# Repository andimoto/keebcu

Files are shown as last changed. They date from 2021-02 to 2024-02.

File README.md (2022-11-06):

# keebcu - a customizer for 3d printable keyboard cases

## Keyboard Customizer

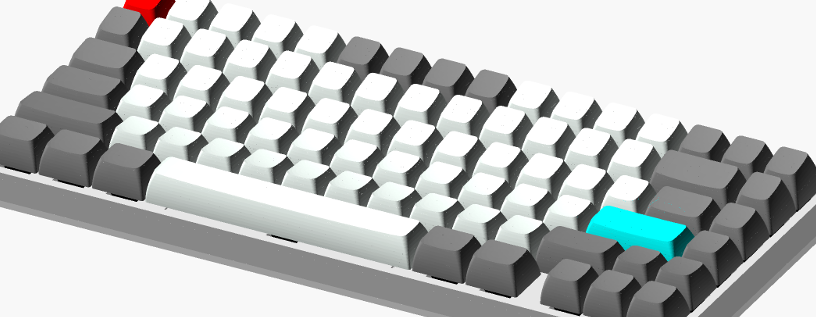
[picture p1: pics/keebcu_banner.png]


### TL;DR usage
```
- clone this repo: git clone https://github.com/andimoto/keebcu.git
- get OpenSCAD (I used 2021.01 and 2019.05 as appImages on Linux).
- open the template_to_copy.scad file in OpenSCAD (or copy and rename it for your own custom layout)
- uncomment 'mainCase(<layout>)' line at the end of the file to check what your are doing
- start customizing your layout (place switch holes and set colors of your keycaps)
- set screw holes where you want them or add even more of them (don't place screw holes near risers on the bottom)
- set usb and pcb values
- set or unset fRowSeparator to move F-Row up
- depending on your printbed size, set where to cut the keyboard case ('cutAfterUnits' & 'spacebarCut')
- (optional) print critical parts of the case like space bar, parts with other stabilizers or usb and pcb area to test everything fits
- generate all necessary model files you want to print by uncomment the proper module call or run the build.sh script
- save as stl file, print and assemble!
- checkout, build and flash firmware firmware https://github.com/andimoto/qmk_firmware/tree/andimoto-keyboards/keyboards/andimoto
```

#### Notes
This is based on *Parametric Cherry MX Mounting Plate for Mechanical Keyboards* by rsheldiii
http://www.thingiverse.com/thing:573578

## Description
This is a OpenSCAD Script for customizing a keyboard with a specific layout. It is designed to show a simulation on how the keyboard could look like by adding keycaps from KeyV2 project by rsheldiii. **So download OpenSCAD and start building your keyboard ;)!**

I designed the keyboard to be printable on smaller 3d printer build plates like Prusa Mini. Therefore, it is possible to configure where the keyboard should be cut by the script with 'cutAfterUnits' variable. With this, it is possible to print a keyboard on smaller printers. The "smallTKL" design is the biggest layout I can print for now. If you have standard size printers like Prusa MK3 or Ender 3, etc, you may print normal TKL or even 100% layouts, eventually :).
The cut will always be around the switch holes. This gives good stability when glueing the parts together. Before glueing, the parts may need some sanding work, etc. Just check that both sides fit to each other without bigger space in between.
(In theory, it should be possible to cut the keyboard into 3 or more parts. Therefore, new modules should be created and the pieces can be calculated by using difference function. This should enable printing bigger sizes like TKL or 100% on smaller printers)

I glued the parts together with Revell CONTACTA glue because of its fine needle which is very practical. Any plastic glue will work. I broke one of my prototype boards for testing and they are pretty stable if glued properly :). I had to use some force for it. Just be sure the case parts are glued well together!

#### Notes
This Keyboard Customizer for OpenSCAD is in "usable" state now, and you can customize your keyboard :). But there are still some imperfections and "bugs". I'm testing several layouts, like normal sized boards to macro pads, etc., from time to time.

Please double check measurements and fittings of your keyboard layout. You first may print some critical parts for testing the model.
The available keyboard models (in stl directory) should work and have been printed by me on a Prusa Mini. I can not give any guarantee on the correct functionality of this script.

### Current designs available
```
- andimoto7583 (printed, documented wiring, firmware ProMicro)
- andimoto6061 (not printed)
- andimoto6064 (printed, documented wiring, firmware ProMicro)
- andimoto_smallTKL (printed)
- andimoto_smallTKL_iso (printed, documented wiring, firmware Teensy2)
- andimoto75Q1iso (printed, documented wiring, firmware Teensy2)
- andimotoTKL (not printed)
- andimotoTKLiso (not printed)
- macropad
- numpad (firmware ProMicro)
```

__Note:__
```
7583 is -> 75% layout with 83 switches.
6061 is -> 60% layout with 61 switches
smallTKL is TKL keyboard with one missing column
75Q1iso -> 75+% with Keychron Q1 Layout
TKL - ten keyless
etc.
```

## Create your own keyboard layout
You can copy the file "template_to_copy.scad", rename it and start configuring your own layout. By uncomment the module calls at the end of the layout file, it is possible to create each part like "right & left case", "right & left lid", and also risers. It is also possible to create the whole keyboard itself in one piece if you can print bigger parts.

If you want to simulate the keyboard with keycaps and its colors, you can clone rsheldiii's KeyV2 Repository
( https://github.com/rsheldiii/KeyV2 ) in parallel to this repository (thisRepo/..).
The SCAD script will include "../KeyV2/includes.scad". So just put it into the right directory.
Keycap styles can be replaced in the module "KeyboardSim('layout','simulation true/false')" itself. See KeyV2 Wiki for available keycap profiles and documentation.

So you can change the colors and have a look at how your keyboard may look like!
You can add more keys into the array, but maybe the case will not fit automatically. Adjust 'height' and 'width' of the case, then.
I will try to implement some more automatic functionalities from time to time.

The keyboard layout is defined in an array. In the template file it is called "template_ansiUS_7583" for example.
It describes (in Units):
```
    [ [xPos (Column) , yPos (Row)] , key size (in Unit), color ]
```

A unit is the size of the cutout for a cherry mx style switch. So, for example, a normal key is 1u,
backspace is 2u or spacebar is for example 6.25u. The size of the cutout for the switch is defined as 'lkey'.

You need to configure 'hight' and 'width' of the case in summury of units. For example: a 5x2 macropad would have width of 5 and a height of 2. These variables are necessary for calculating case sizes. Maybe this will be automated, as the information should be calculatable from the layout array.

The 'layout' array variable holds all integer values, including x.5 values in y direction (like numpad enter). Any else switch hole needs to be integrated in the function/module 'extraCutoutHook'. See ISO layout for an example. In this module any 'unaligned' switch hole can be integrated. Properly to that, the module 'extraKeySimHook' allows to integrade additional simulations, like special keycap simulation like IsoEnter, etc.

After configuring your layout, you can adjust and modify the array 'screwHoleArray' to set the scew holes to the right place you want them to. The lid will also use this array, and thus, the screw holes will fit automaticaly to the case. The standard screw size is 3mm. The length depends on the case height, but I used 3x8mm cylinder head screws for my keyboards.

It is also possible to modify the pcb dimensions with the 'pcb'-values. Available sizes for Arduino Pro Micro and Teensy2 are included. Just change the comments to select the right one. I recommend to measure your pcb anyway and check dimensions. You can also move the whole pcb and cutout for usb connection in X direction by setting 'pcbShift' with a positive or negative value.

Generating risers for the keyboard can be selected with true/false and adjusted in width and length/depth. The colors of the risers and of cource the case and lid can be set after the screw hole array, at the end of the layout file.

With the variable 'fRowSeparator' you can select if the F-Row or the most upper Row (key[0][1]==0) will be moved upwards by a half key unit. See example 'andimotoTKL_iso'. When selecting 'true' some modules will call 'getExtraFRow()' function to get the value to move F-Row upwards.

If the keyboard should get a skirt you can set 'skirtSelect' to true. This enables calculation of an additional skirt around the keyboard. The parameters 'skirtX', 'skirtY' and 'caseRadius' define the skirts dimensions and the radius of the edges.

## Build STL Files
I added the script 'build.sh' for building all necessary parts of a keyboard at once. It reads 'conf/module-calls.conf' and places each call at the end of the keyboard file to render it and safe it in the stl directory. The output is saved in stl directory under the keyboard name.

```
NOTE: openscad command should be in $PATH or the environment variable OPENSCADBINPATH should be set to the OpenSCAD binary.
For example:
                export OPENSCADBINPATH=/home/<user>/<pathToBinary>/OpenSCAD-2021.01-x86_64.AppImage
```

```
build.sh parameter:

./build.sh <keyboard name> <config file>
    - keyboard name: name of the keyboard file without .scad extension
    - (optional) config file: mymodules.conf (any file name is possible, just add the proper syntax)

for example:
    ./build.sh andimotoTKL

    or

    /build.sh andimoto6061 myModuleCalls.conf
```

```
NOTE: do not remove this line from the keyboard file and do not place this line in between the configuration variables

              /* ###################### BUILD_LINE ########################*/
```

### build.sh description
The build.sh script checks if OpenSCAD binary is available. If not, user has to set OPENSCADBINPATH to point to the binary.
Then it checks parameters. The 1st parameter is necessary and tells the name of the keyboard to build. The script then appends .scad extension automaticaly and uses the name for the output directory. No keyboard file name provided, will stop the script and return an error. Then it checks optional parameter of config file. Default config file will be used if no 2nd parameter is given.

Each keyboard file has a separator at the end: "BUILD_LINE". The script greps for the line number of the separator and prints out the keyboard file until this line number. This output will be saved in an temporary directory which will be removed after build. Also, and output directory will be generated to save stl files in it.
Then it places each module call from the config file at the end and calls OpenSCAD with the generated file to render the stl part. After this it places the next module call and generates the next stl, an so on.

You can add your own config file with the module calls you want and call the build.sh script with the config file as 2nd parameter. If no 2nd parameter is given, the script uses default config file 'conf/module-calls.conf'. The script greps for 'module' and separates the line at ':'. The last part will be used and appended to the created scad file.

```
config file syntax:
  module1: mainCase(layout);
  module2: lidR();
  module3: myOwnModuleCall(withParam);
```

__This was only tested on Linux Mint 19.3 (Ubuntu 18.04) and Linux Mint 20 (Ubuntu 20.04).__

## Parts needed
- Printed Keyboard Parts
  - Case
  - Lids
  - Risers
- __Cherry MX Style switches__
- __Costar Stabilizers__
- __Fancy Keycaps__
- __Teensy2 or Arduino Pro Micro__
- 12x Cylinder Head Screws 3x8mm for lids
- 20x Cylinder Head Screws 2.5x8mm for frame (if frame is selected)
- Thin wires
- 1N4148 diodes

__Note:__ Parts can be bougth from ebay, amazon, etc. There is a great choice, but also many things are not available or in stock...

## Assembly
- Use sandpaper and a scalpel to clear the surface where parts get glued together. Double check if parts do not block each other.
- Glue the two case parts together carefully. Place them on a flat surface and put some books on each side, then put some glue into the rills.
- Wait until it is dry and put some more glue on it if needed.
- After some drying time you can put in the switches (it is possible that this will bend the keyboard)
  - Maybe you need to add more glue when keyboard is bended
  - Switches which will have stabilizers should be set with the champfer downwards. Champfer is where LED placement is on the switch. Then the stabilizers have space inside the keycaps.
- Solder switches and diodes together (see directory wiring_sheets)
  - Checkout qmk guide for handwiring -> https://beta.docs.qmk.fm/using-qmk/guides/keyboard-building/hand_wire
- Solder the controller onto the keyboard matrix and place the pcb inside the pcb holder of the lid.
- Build, flash and test your firmware (you can use this for testing https://keyboardchecker.com/)
- Screw all parts together and place the risers if you need them (I recommend gluing the risers on the lids and then assembly them to the case)
- If you use Costar Stabilizers, place the stabilizers downwards.
- Have fun with your keyboard and start building your next keyboard ;)

## Printing advises
- Use brim for keyboard case. As there are many holes, the plate adhesion can be weak and the corners can rise up a little bit.
- Be careful with color changes. If color change is only at height of case stabilizer (not keycap stabilizers!!) or screw holes, there can be problems when screwing on the lid. I broke the top part of the scrw cylinder where the color change had no good adhesion the other layers. I recommend to do the color change at the last layer of the keyboard cases plate as seen [here](https://github.com/andimoto/keebcu/tree/master/pics/img/screwHolesColorChange.jpg)
  - Place color changes on the upper layer of the plate of the case. With this the walls have more adhesion on previous layers as seen [here](https://github.com/andimoto/keebcu/blob/master/pics/img/IMG_20210406_151457.jpg)
  - Note: though this issue may be fixed with the oval spacers for the screws, double check the stability of the screw holes by printing a small prototyp with color change where you want it.
- Notice, when placing the switches into the plate, the keyboard case will bend (mid up, sides down) there is the variable 'switchHoleTolerance' which you can modifiy if needed. This could reduce this kind of bending, but also make the switches more loose.
- Normally the lid parts do not need any brim.
- Check if your printer prints right-angled. I had issues with my Prusa Mini printing exact squared parts. More info [here](https://forum.prusaprinters.org/forum/how-do-i-print-this-printing-help/how-to-fix-bending-of-a-box/).

## todo
- create selectable space (in y direction) between function row and next rows (DONE: fRowSeparator)
- provide pcb cutout for teensy 2.0 (DONE)
- add delta variable for usb cutout and pcb-holder to move it. (DONE)
- avoid case stabilizer for iso enter and numpad enter (optional)
- add cherry style stabilizer!
- add a selectable skirt to the case (DONE)
- add parametric keebCase (in progress, should be already usable)
- screw holes get crossed by case stabilizer (DONE / screw hole standoffs have also an oval shape now)
- documentation for keebCase.scad (always in progress)
- add build script (DONE)
- other build system (make or docker, etc.)
- test other keyboard layouts like random stuff or ten keys (always in progress)
- make screw stems (spacers for screwing lid in) rotateable (DONE: screwSpacerRotation in degree)
- move inner horizontal case stabilizers in vertical direction (DONE: set caseStabMov Var)

## Wrist rest and Keyboard Case
For each keyboard a wrist rest can be created with the model file wrist.scad. The stl-directory contains a wrist rest for each keyboard which can be printed as you want.
For transportation I designed a case which can be customized in size to fit your keyboard. The case has placeholders for little magnets and gets locked by some kind of bones :).

__Attention: The Keyboard case is still in development state. I just printed some smaller prototypes. But it fits well so far. Need to check magnets.__

## Firmware
For firmware please see https://github.com/andimoto/qmk_firmware/tree/andimoto-keyboards/keyboards/andimoto

The qmk_firmware fork contains everything to build the firmware for the provided boards *andimoto7583* and *andimoto_smallTKL*.

**Attention: The Pro Micro is "normally" suited for layouts with up to 65 switches. I was lazy and did not want to modify the pcb cutout to fit in the teensy 2.0 at that time. So I removed both TX/RX Leds from the pro micro and had 2 extra pins available (pcb may be damaged!!). This enables layouts with up to 84 switches :). Also qmk_layout needs to be squeezed together.**

*I will also add a schematic for soldering the keyboard matrix and the Pro Micro of the available boards.*

Available wiring diagrams for:
- andimoto6064 with Arduino Pro Micro
- andimoto7583 with Arduino Pro Micro
- andimotoSmallTKL_iso with Teensy 2.0
- andimoto75Q1iso with Teensy 2.0

The Arduino Pro Micro clones are very cheap so I used them. More money for fancy keycaps ;).

## Model Gallery
*andimoto7583*
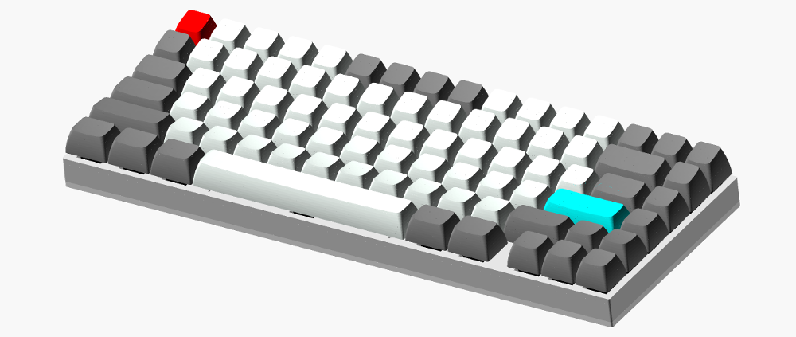
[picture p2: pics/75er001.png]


*andimoto smallTKL iso*
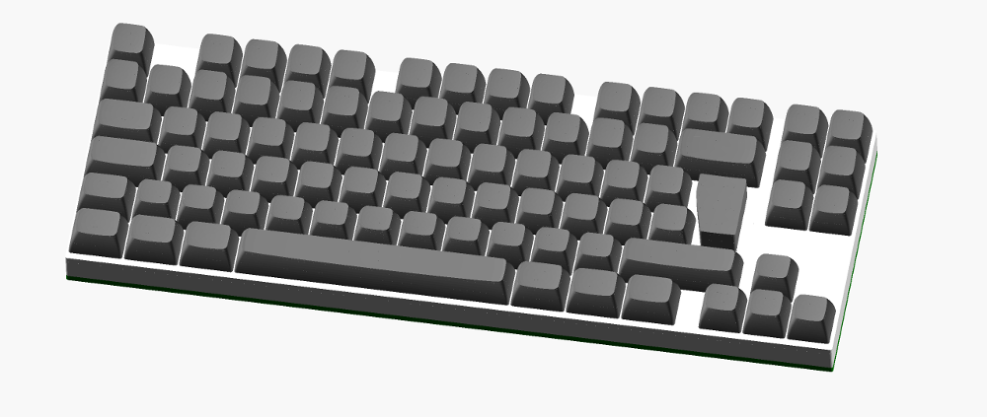
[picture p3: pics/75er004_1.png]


*andimoto smallTKL*
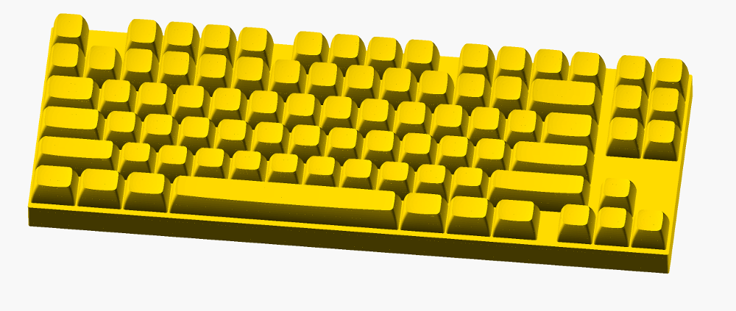
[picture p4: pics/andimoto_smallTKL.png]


*andimoto smallTKL_iso*
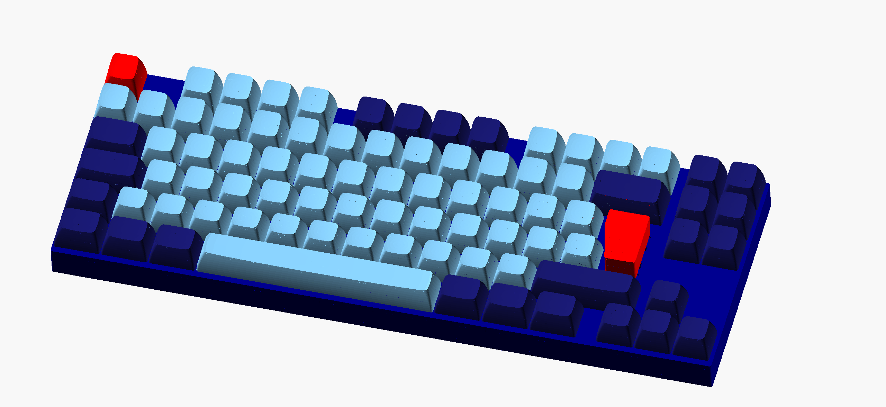
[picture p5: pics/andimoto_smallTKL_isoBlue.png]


*andimoto6061*
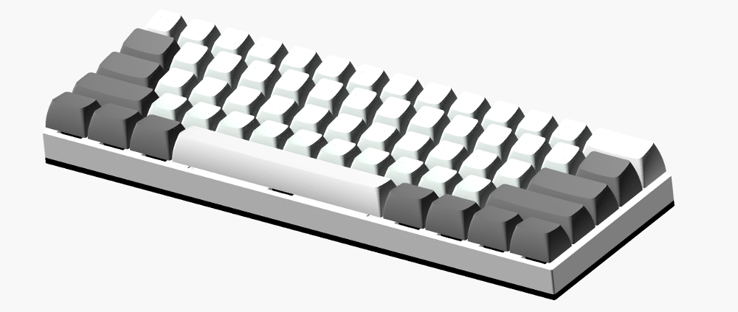
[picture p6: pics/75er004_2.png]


*andimotoTKL*
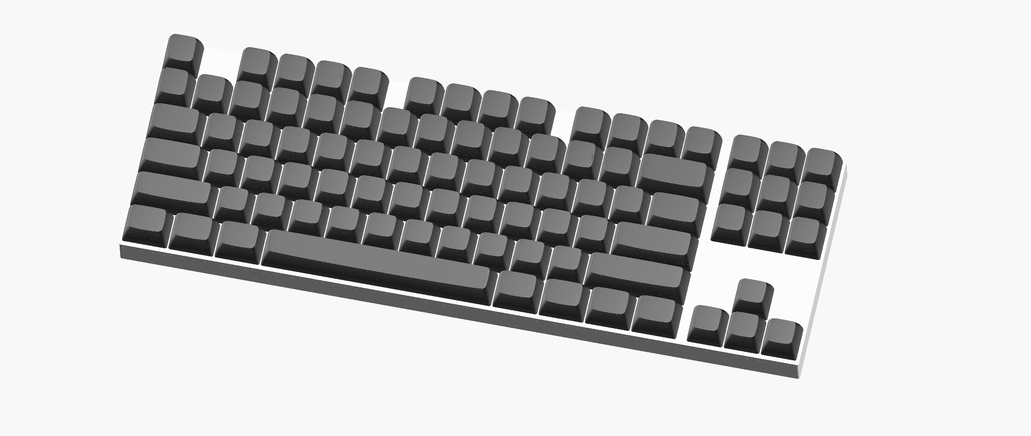
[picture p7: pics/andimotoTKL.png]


*andimotoTKLiso*
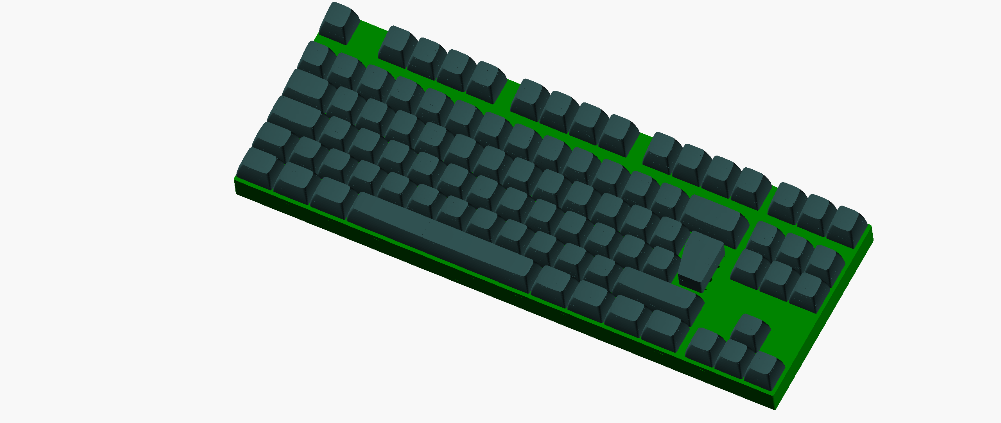
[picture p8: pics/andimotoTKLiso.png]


*andimoto75Q1iso*
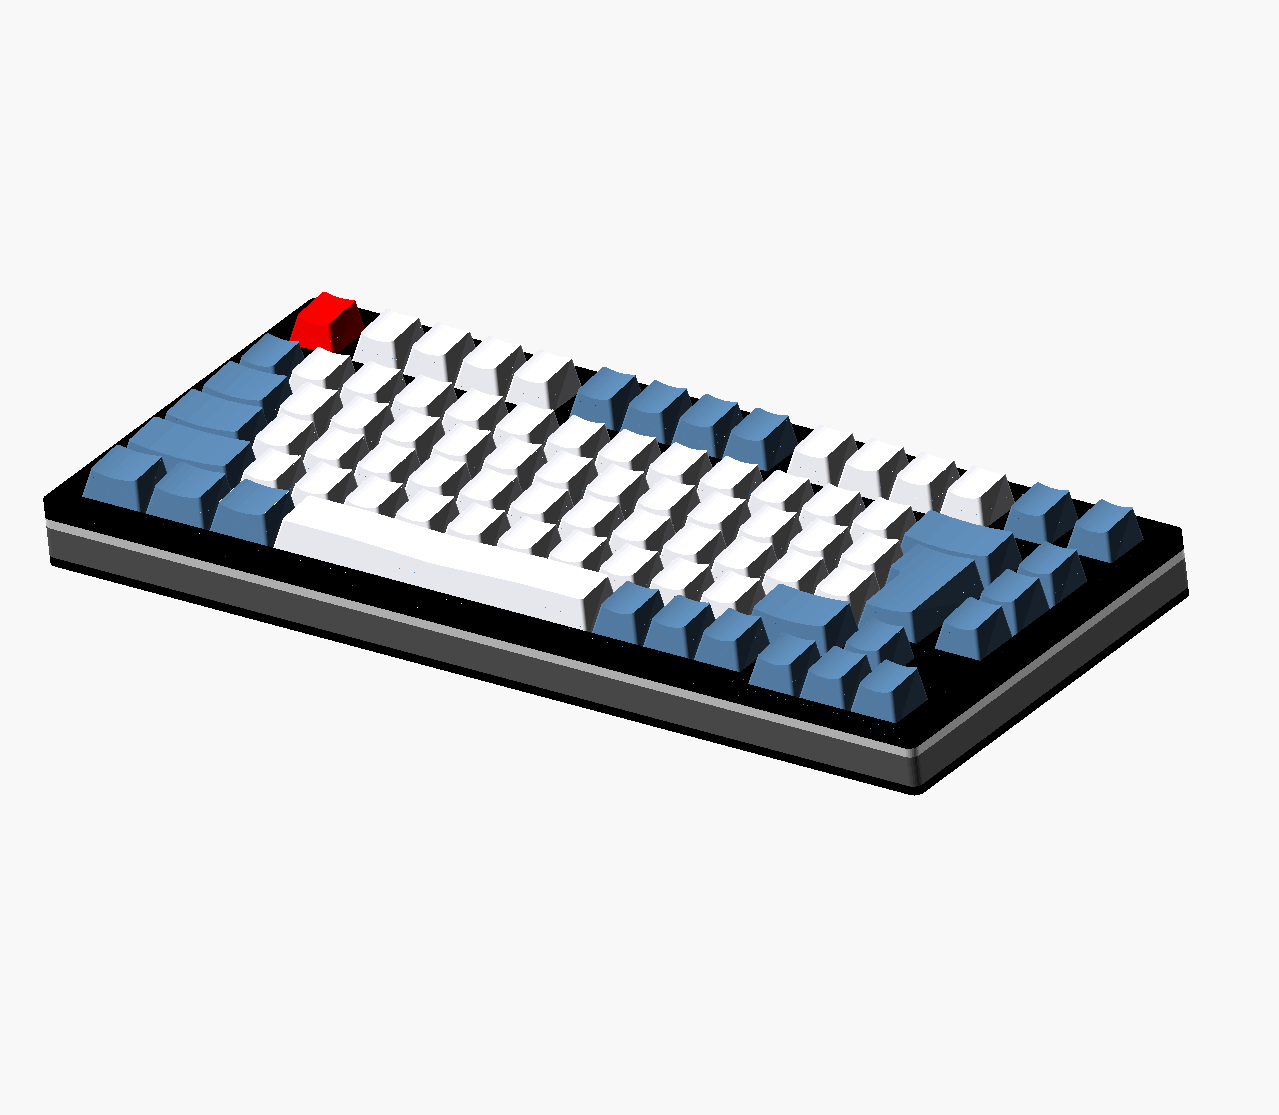
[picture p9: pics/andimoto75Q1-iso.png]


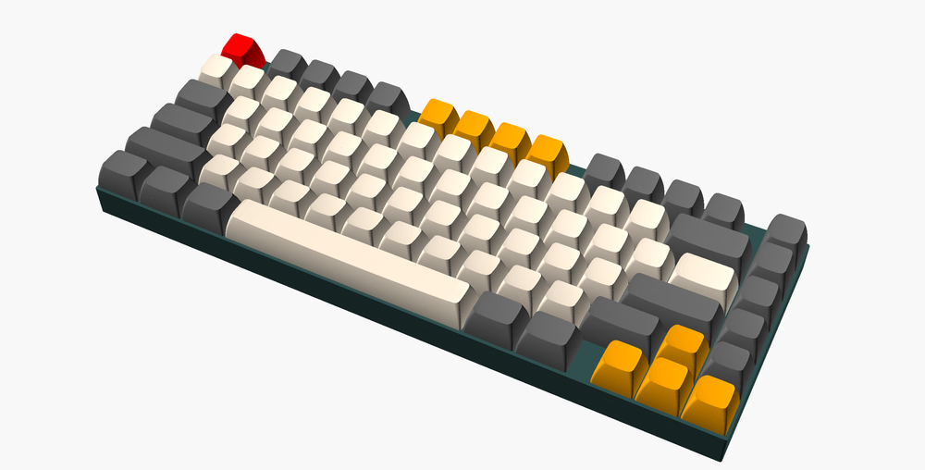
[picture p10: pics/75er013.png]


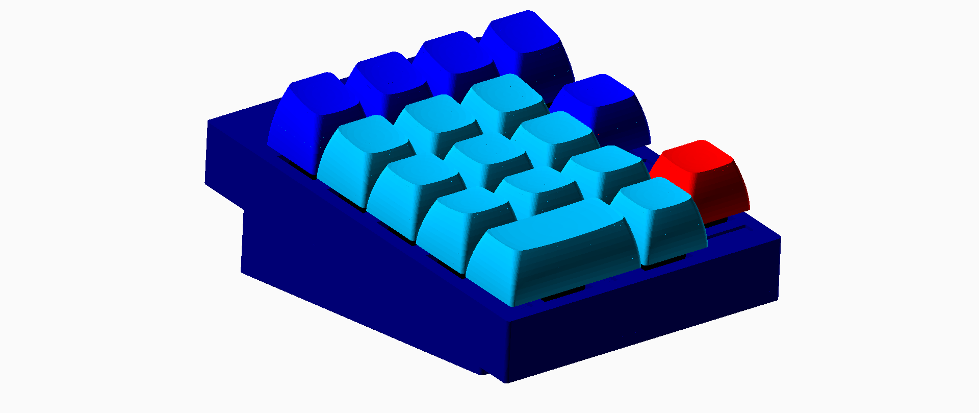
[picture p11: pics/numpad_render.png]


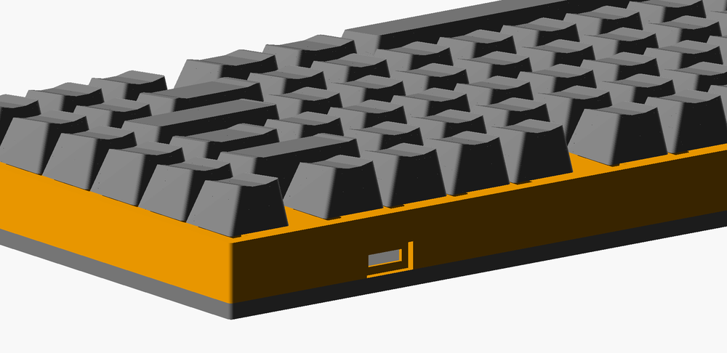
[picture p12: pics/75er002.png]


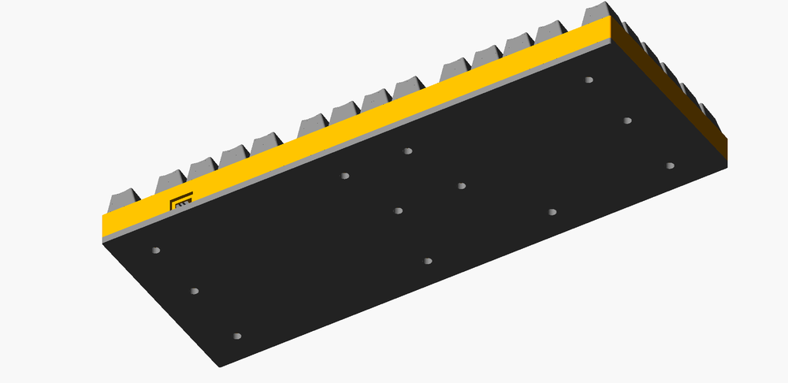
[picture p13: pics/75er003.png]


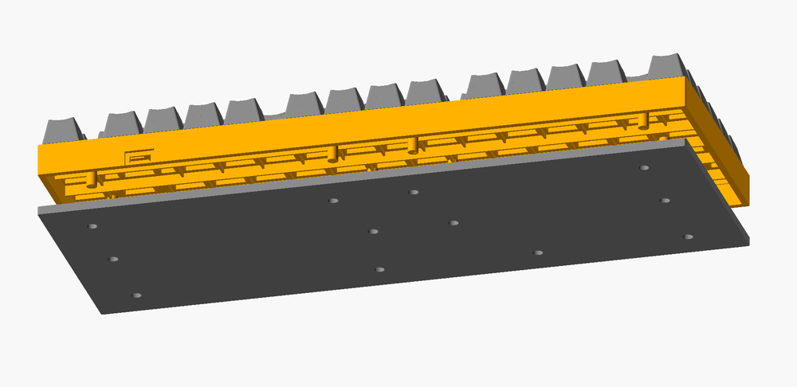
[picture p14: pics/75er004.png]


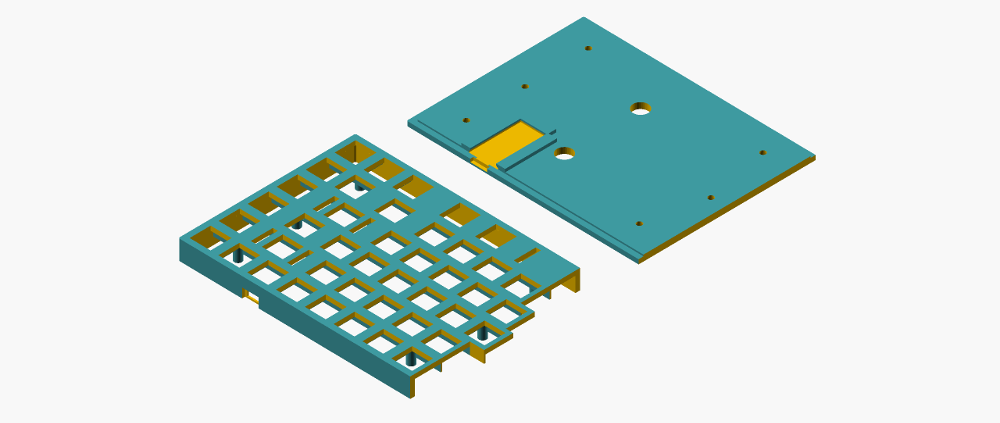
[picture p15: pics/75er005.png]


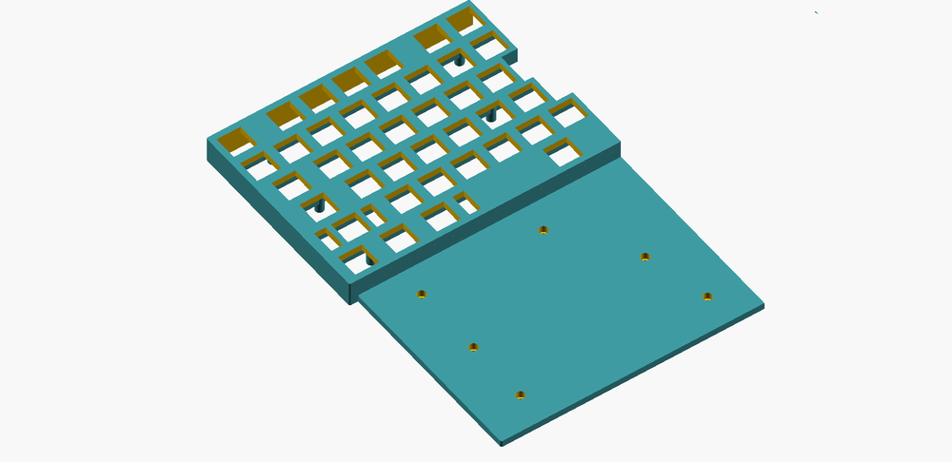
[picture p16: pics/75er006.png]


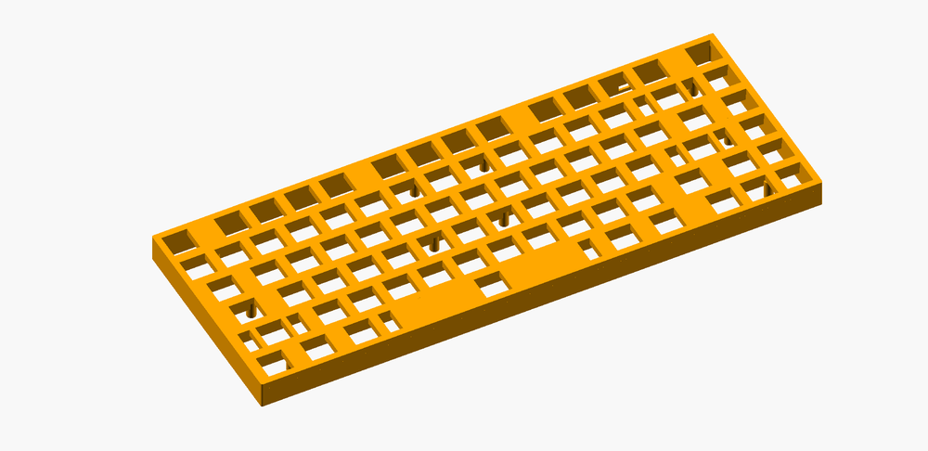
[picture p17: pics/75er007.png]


*andimoto smallTKL_iso case*
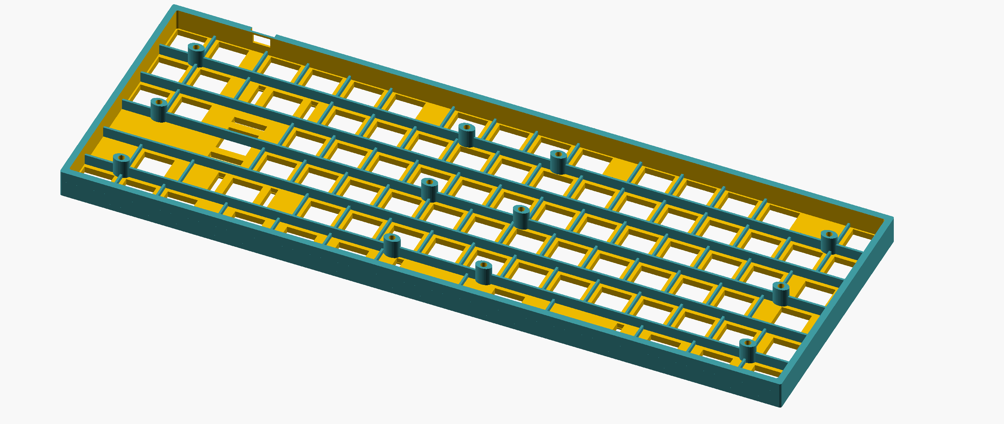
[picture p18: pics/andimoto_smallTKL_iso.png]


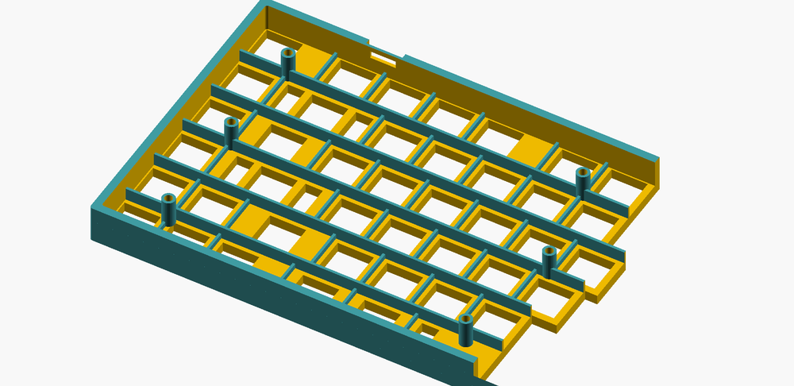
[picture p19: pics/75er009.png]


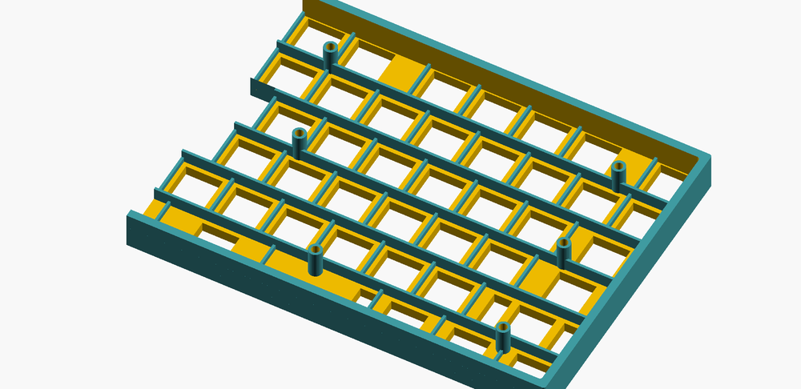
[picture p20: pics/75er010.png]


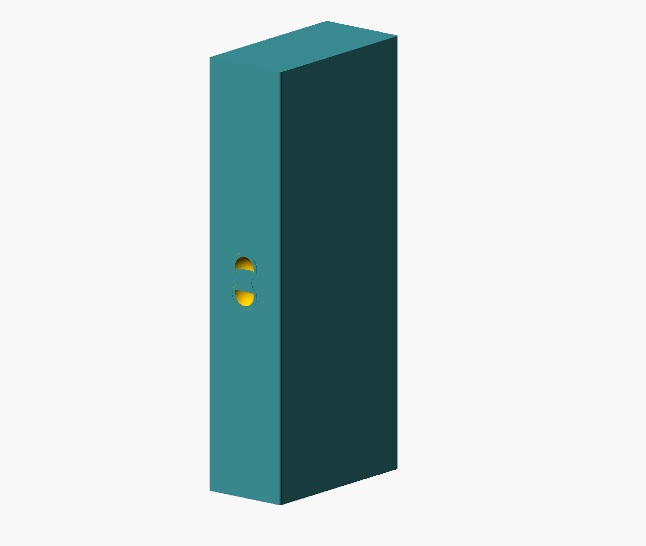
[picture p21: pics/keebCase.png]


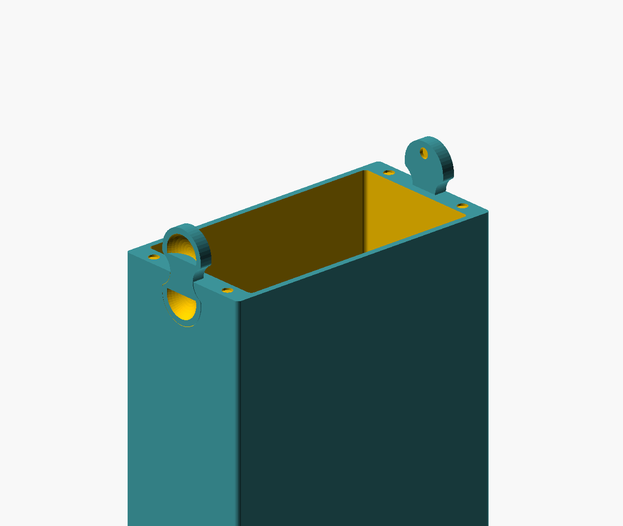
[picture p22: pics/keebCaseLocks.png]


<br>

### -------- ___Reality___ --------

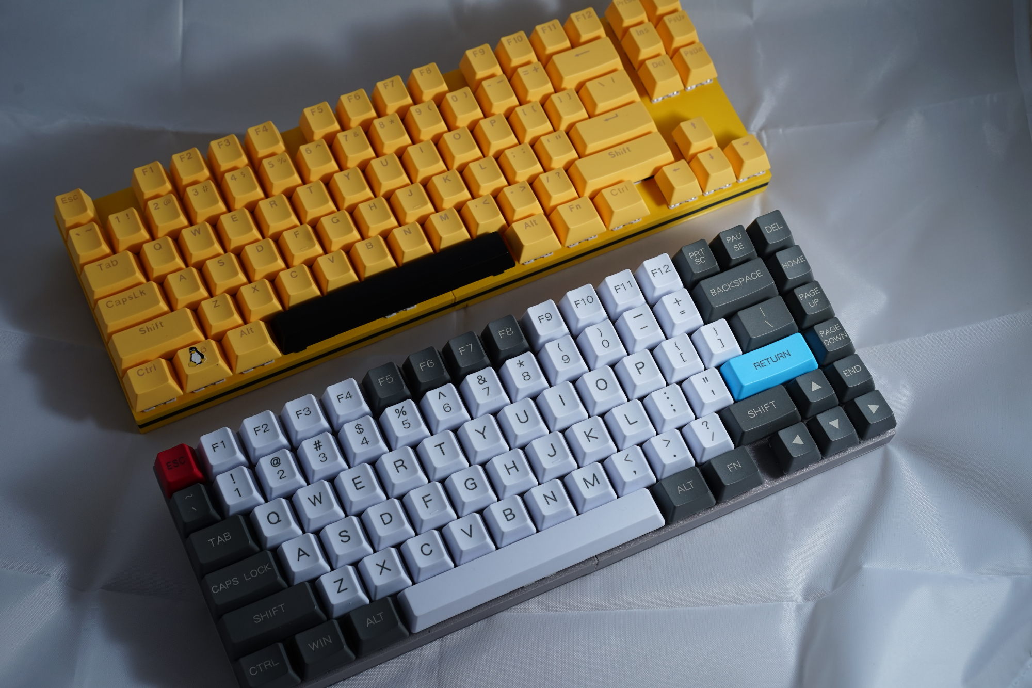
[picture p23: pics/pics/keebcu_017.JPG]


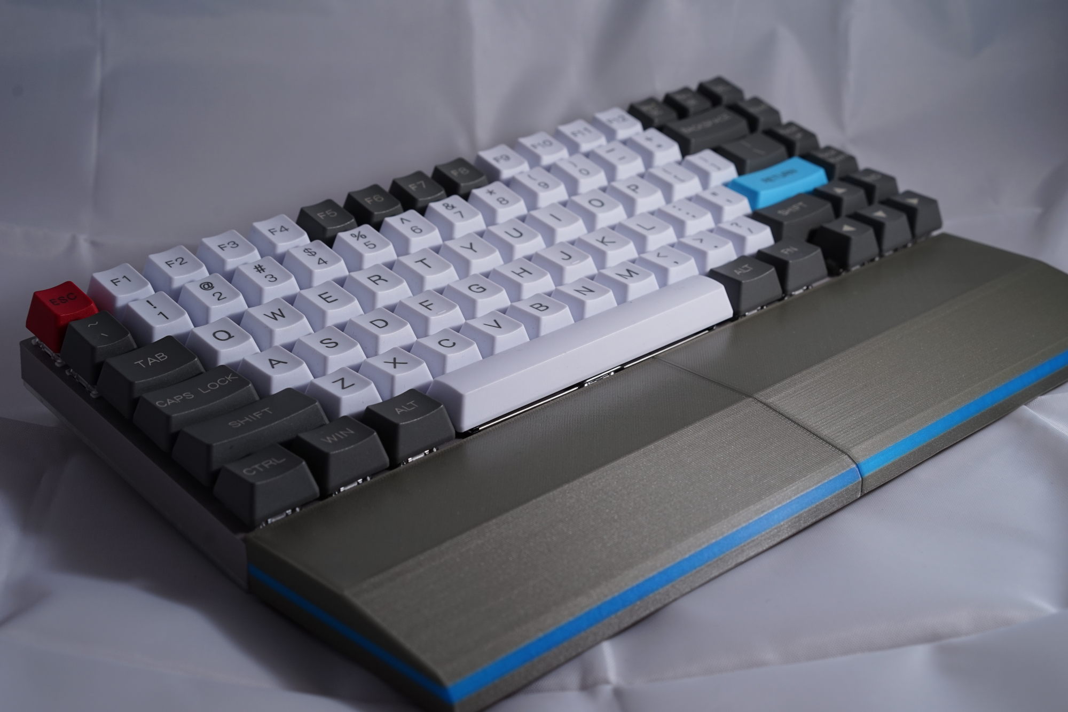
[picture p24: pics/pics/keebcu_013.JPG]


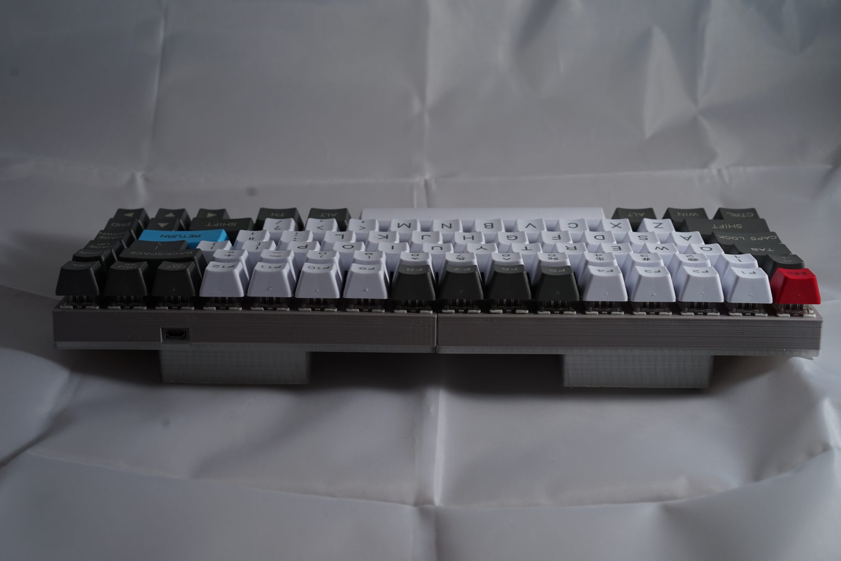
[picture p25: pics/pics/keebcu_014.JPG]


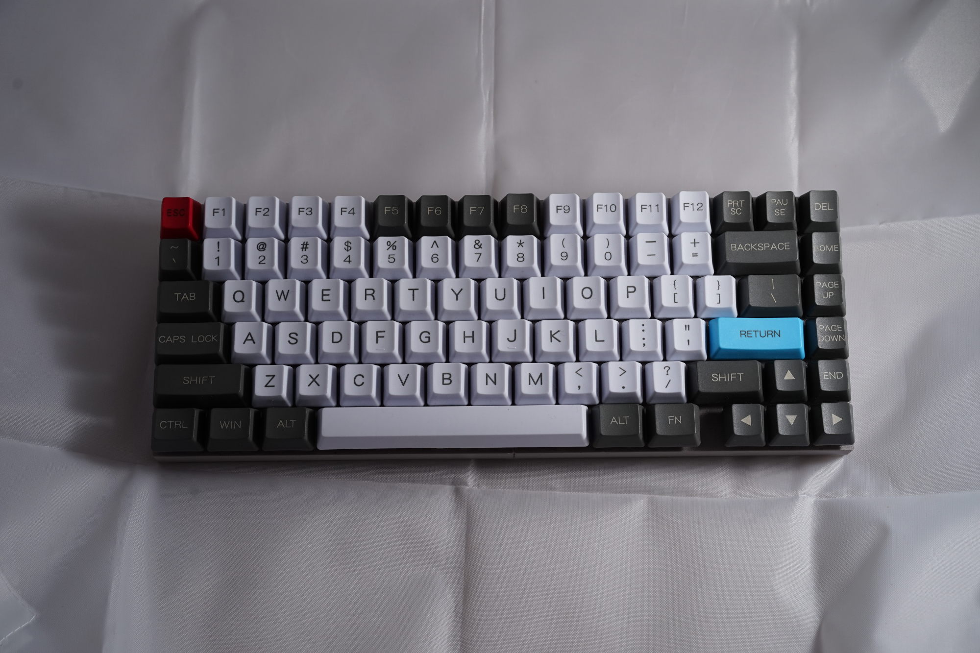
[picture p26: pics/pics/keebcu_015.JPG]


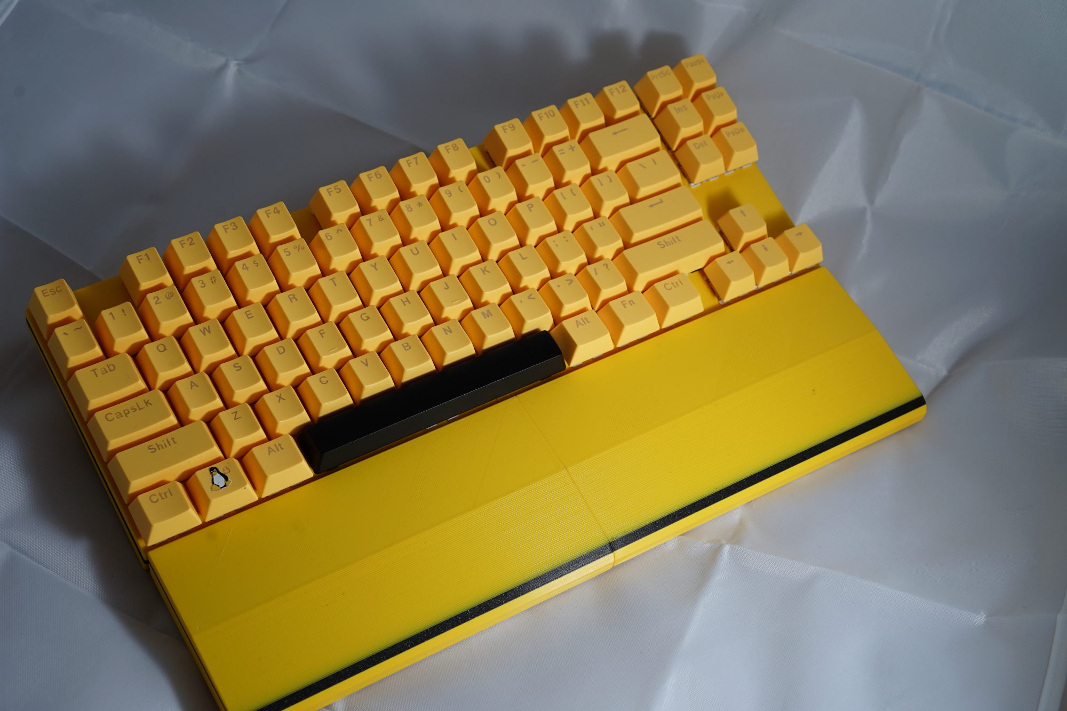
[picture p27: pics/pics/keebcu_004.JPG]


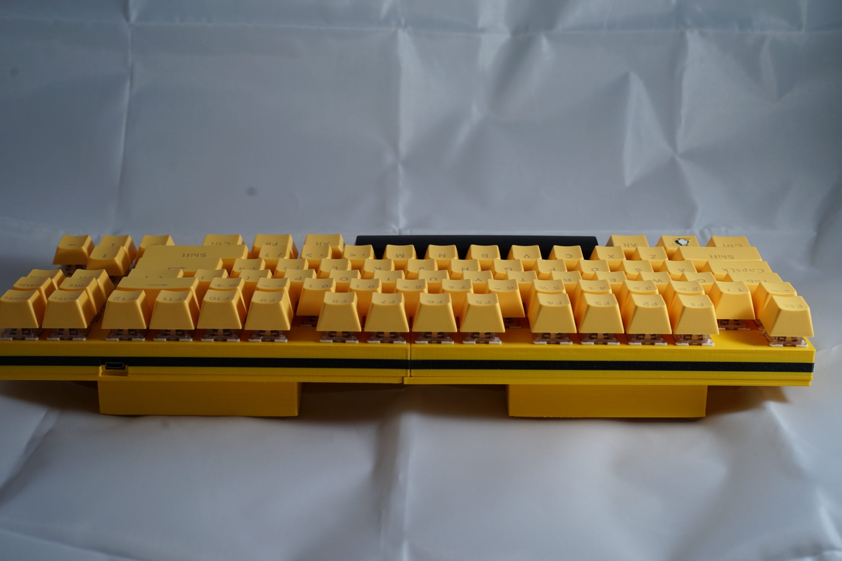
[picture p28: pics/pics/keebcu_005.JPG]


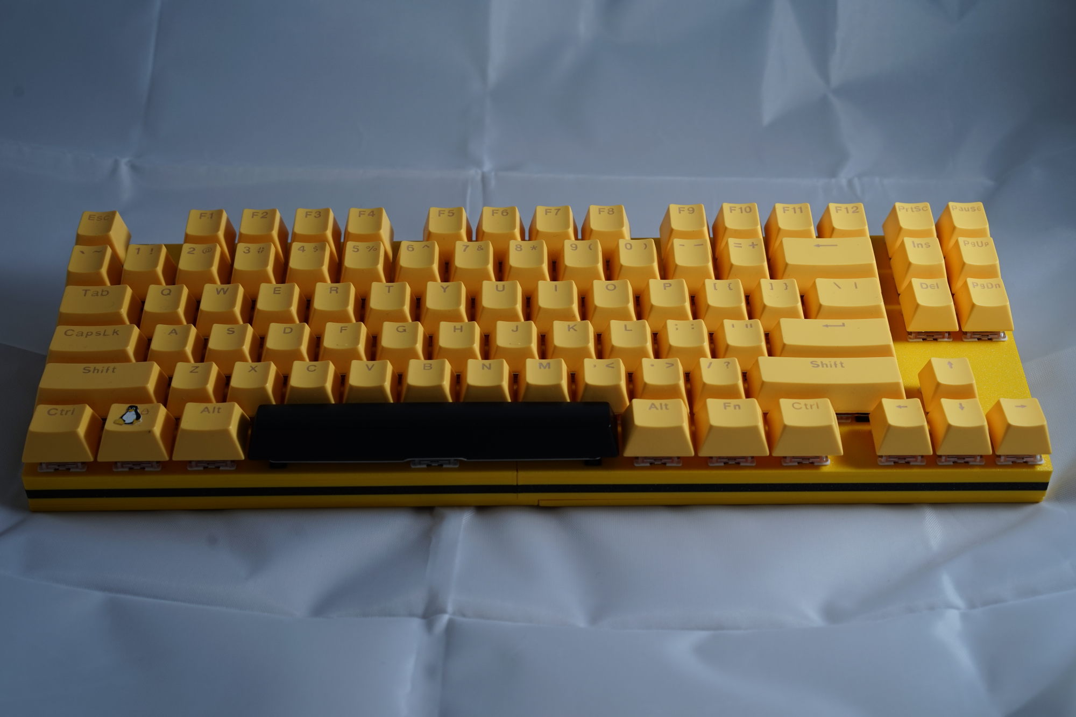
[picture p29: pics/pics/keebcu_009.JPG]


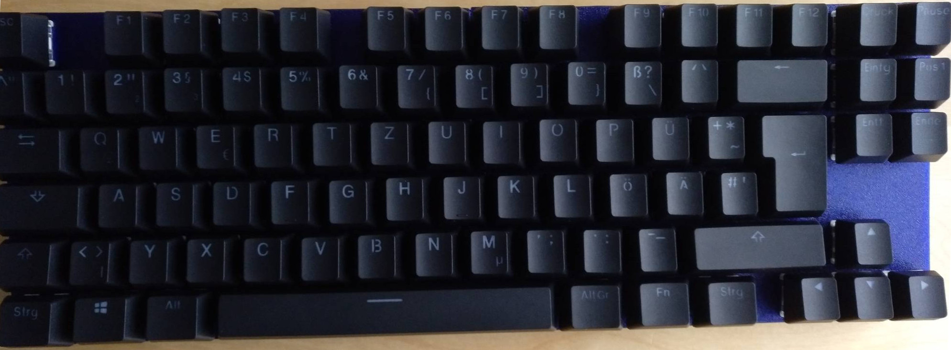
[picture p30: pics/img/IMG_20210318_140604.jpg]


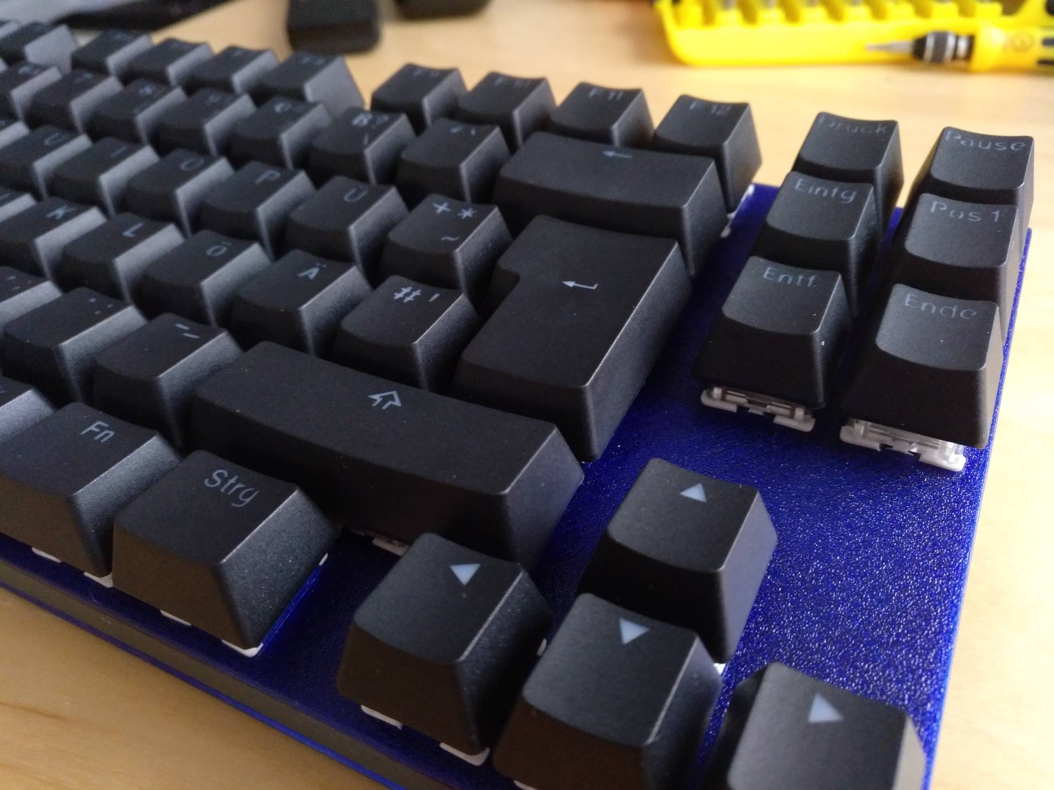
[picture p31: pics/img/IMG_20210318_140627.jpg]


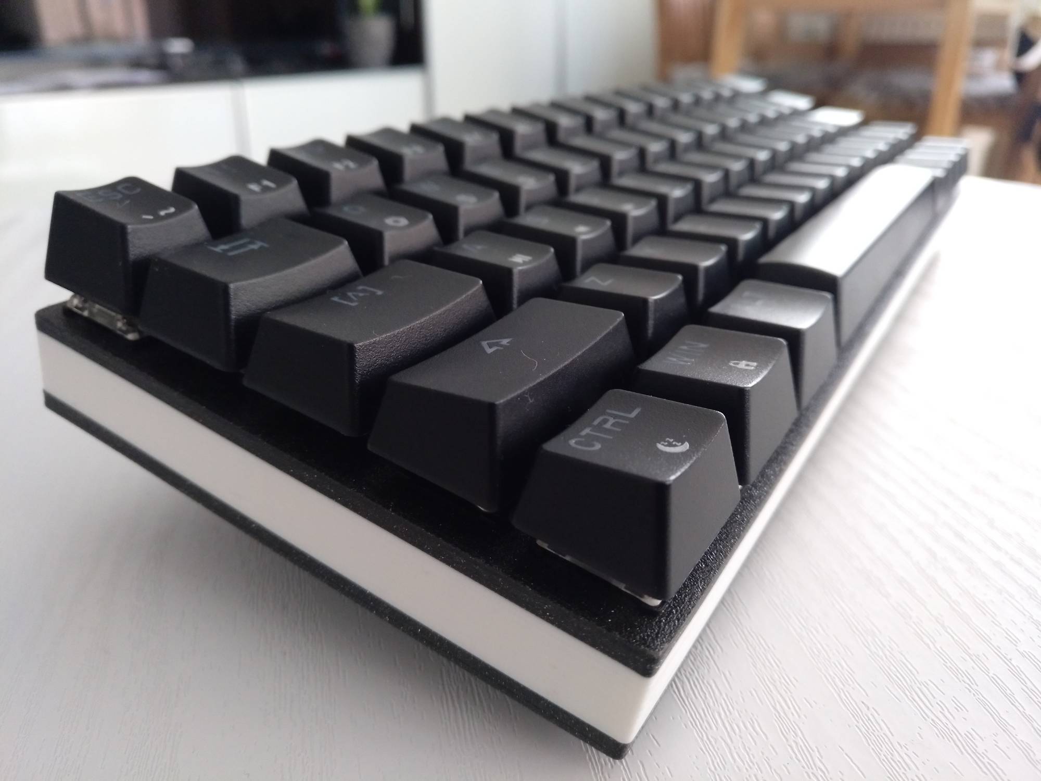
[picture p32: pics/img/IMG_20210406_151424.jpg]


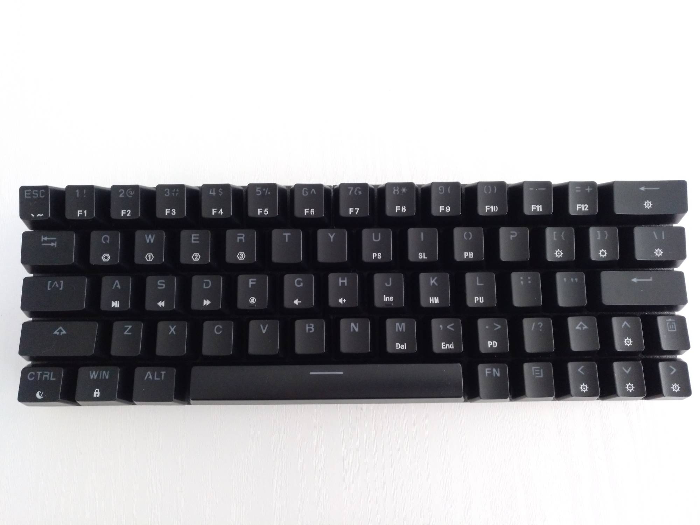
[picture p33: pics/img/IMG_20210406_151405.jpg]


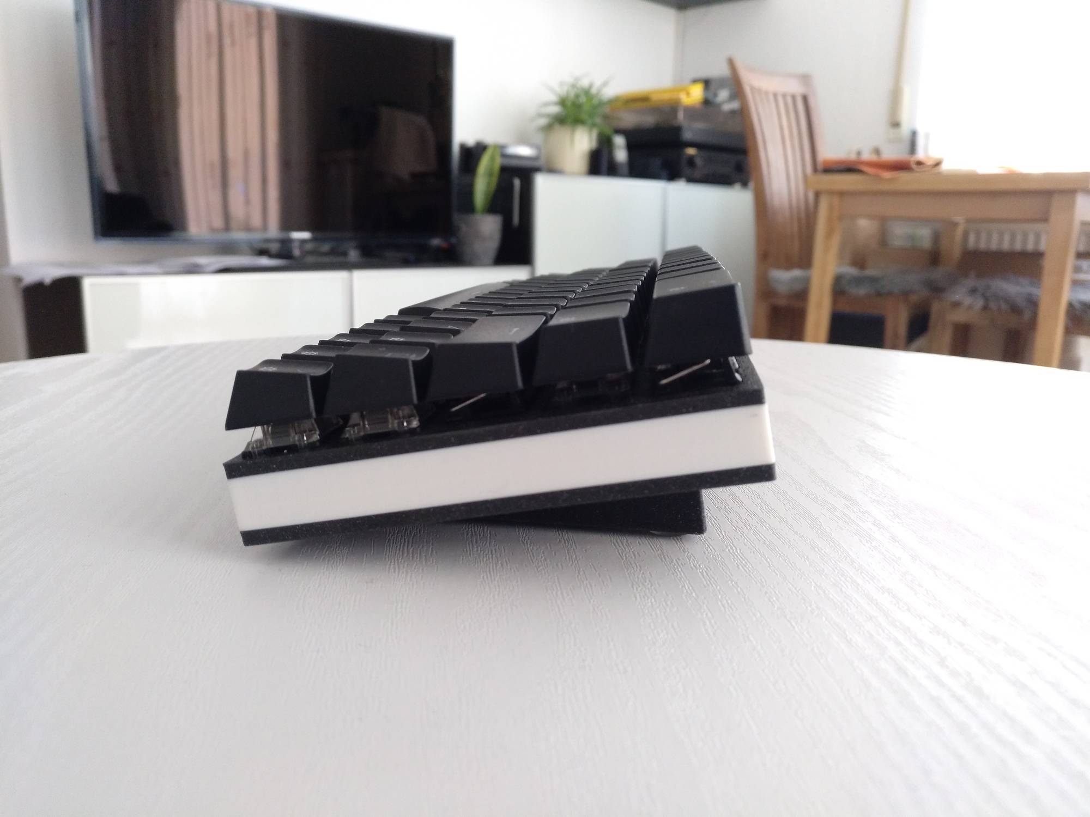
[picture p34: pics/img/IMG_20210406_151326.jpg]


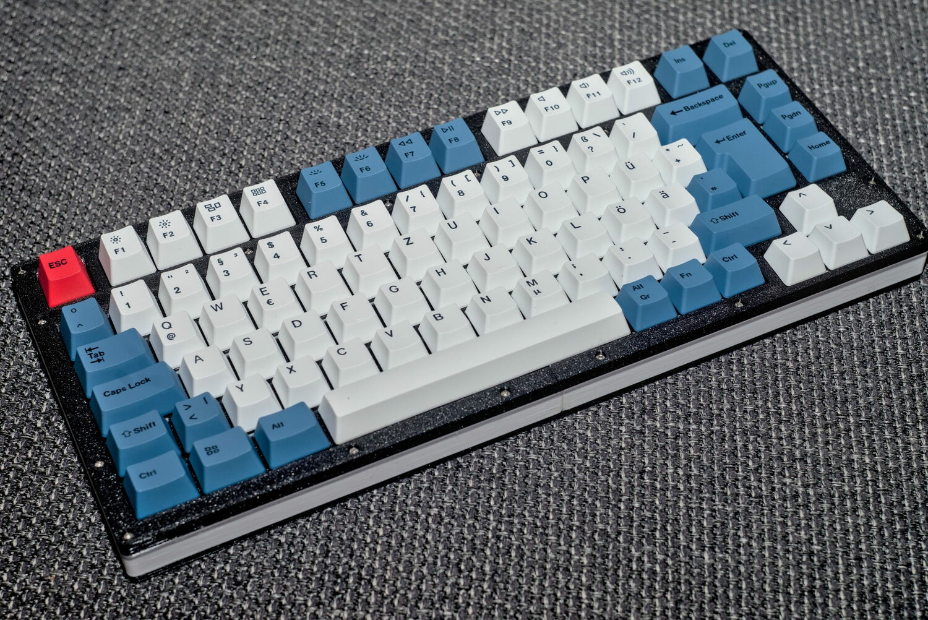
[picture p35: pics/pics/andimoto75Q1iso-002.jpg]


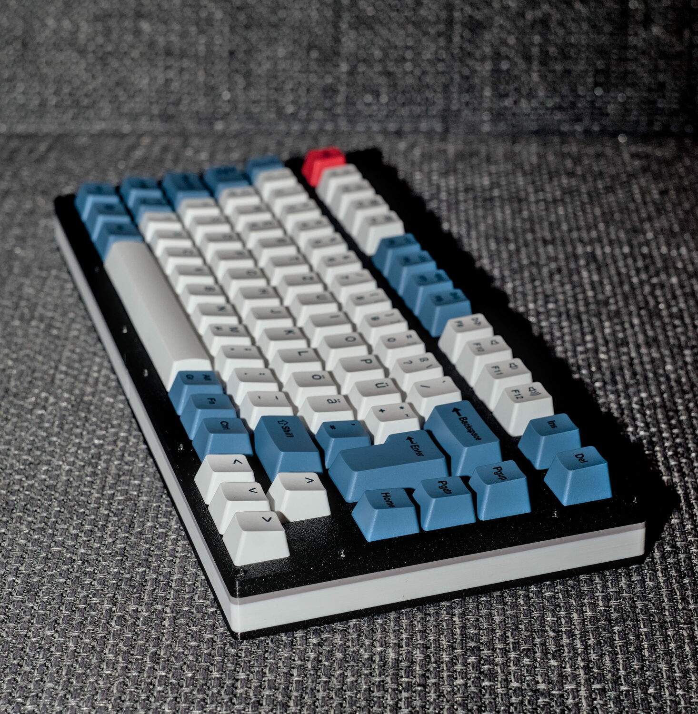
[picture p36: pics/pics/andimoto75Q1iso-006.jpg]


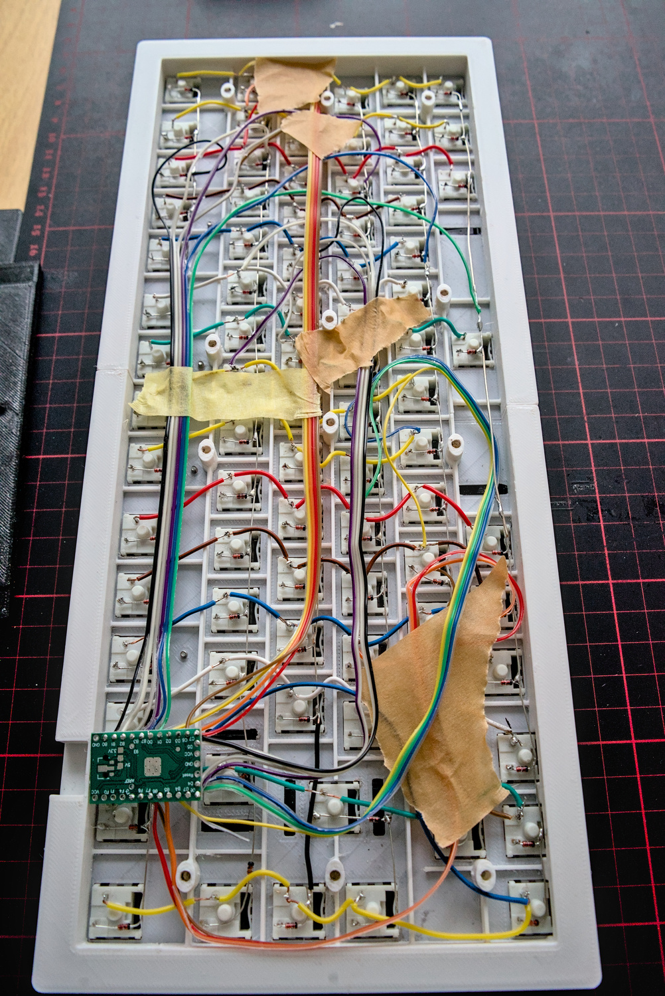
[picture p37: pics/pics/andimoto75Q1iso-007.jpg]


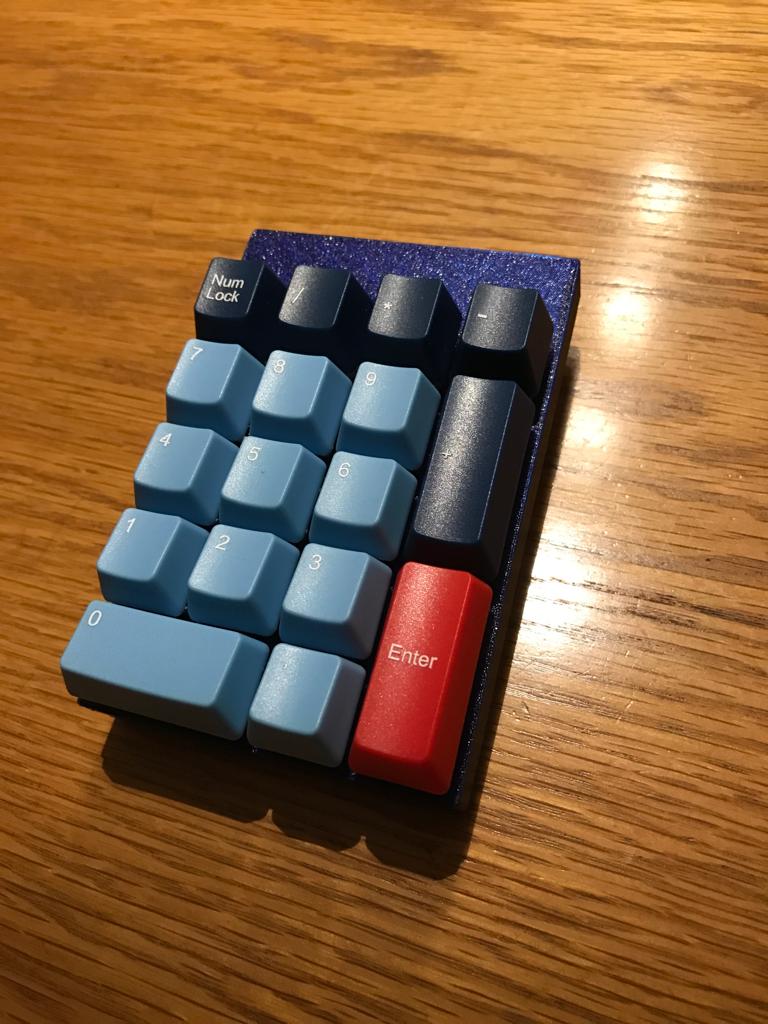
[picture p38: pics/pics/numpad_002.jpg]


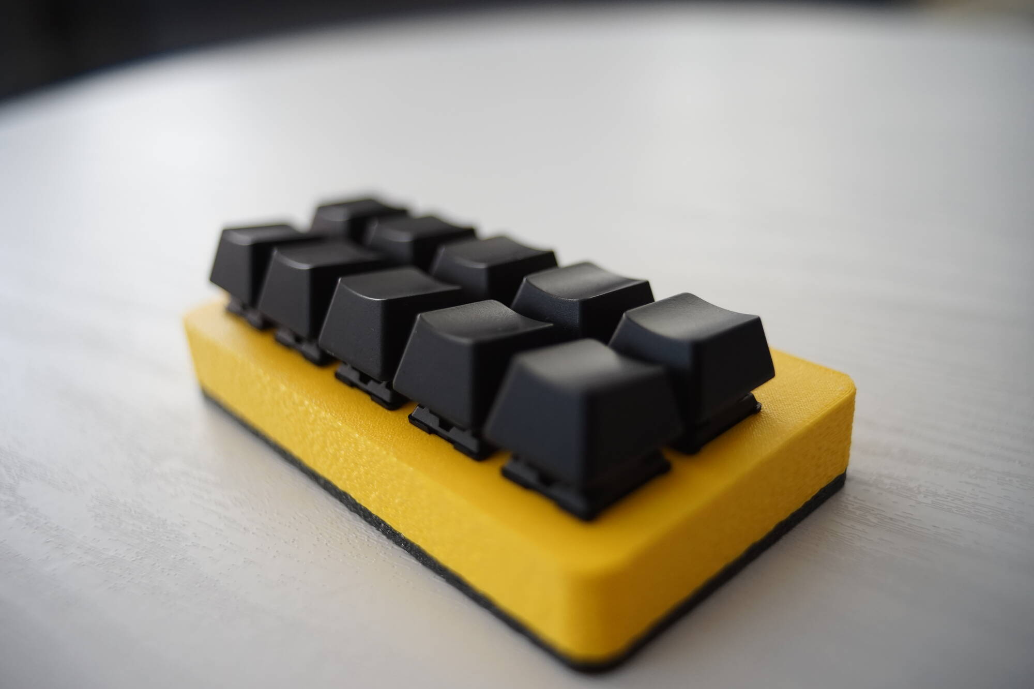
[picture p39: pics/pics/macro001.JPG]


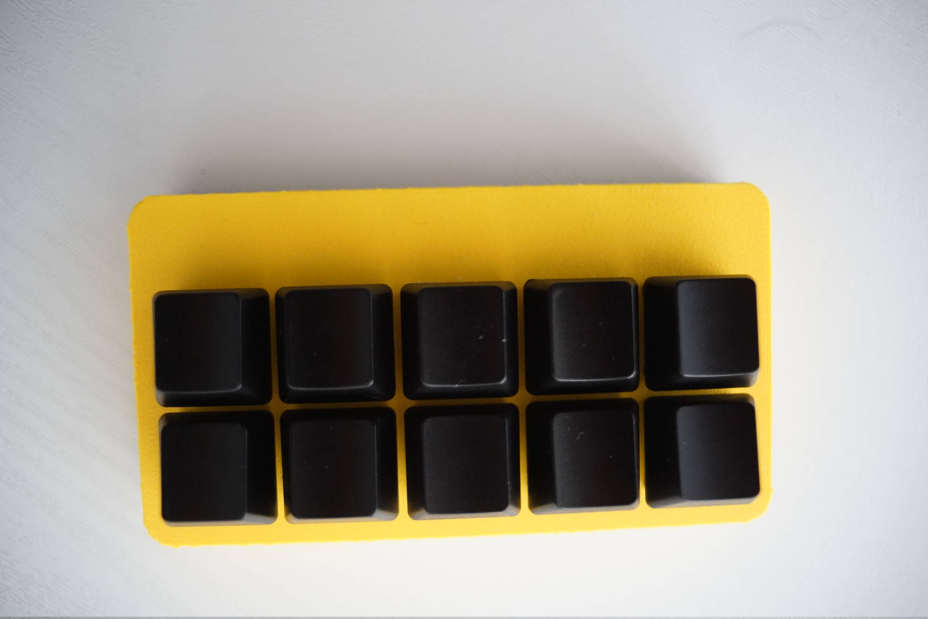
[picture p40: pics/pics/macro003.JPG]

*5x2 macropad printed with fuzzing on outer walls*


### -------- ___Development Process___ --------













# LICENSE

<br />Dieses Werk ist lizenziert unter einer <a rel="license" href="http://creativecommons.org/licenses/by-sa/4.0/">Creative Commons Namensnennung - Weitergabe unter gleichen Bedingungen 4.0 International Lizenz</a>.

<br />This work is licensed under a <a rel="license" href="http://creativecommons.org/licenses/by-sa/4.0/">Creative Commons Attribution-ShareAlike 4.0 International License</a>.

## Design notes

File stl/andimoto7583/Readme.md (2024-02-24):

Added lid without holder for pcb. Just the top of the pcb holder was removed. The pocket for the pcb is still there.
Files are marked with *CNC

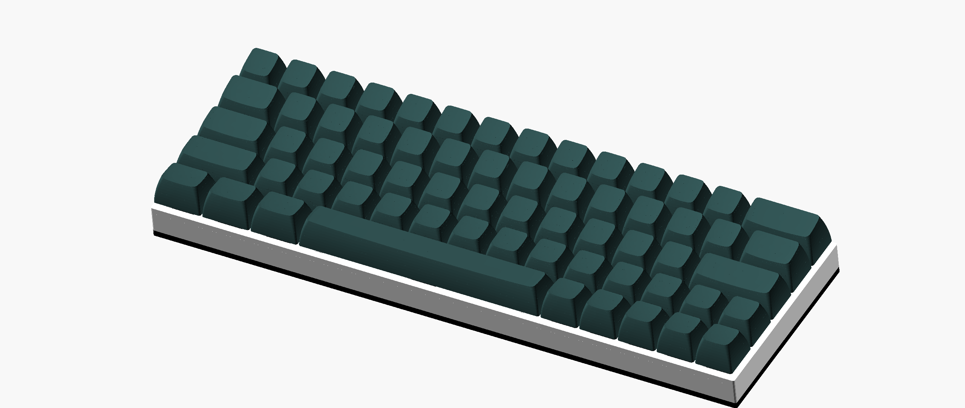
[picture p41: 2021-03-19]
pics/andimoto6064.png

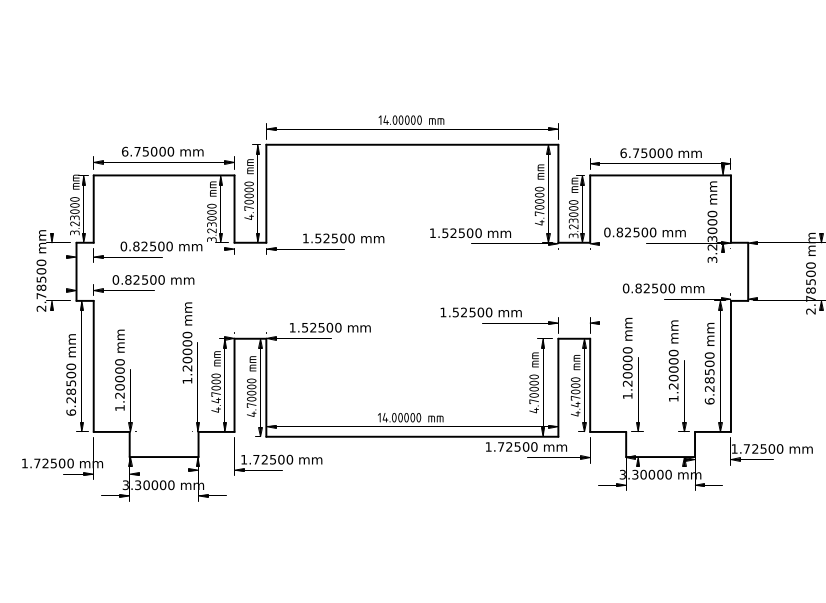
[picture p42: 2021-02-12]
pics/stab-key-sizes-cherry.png

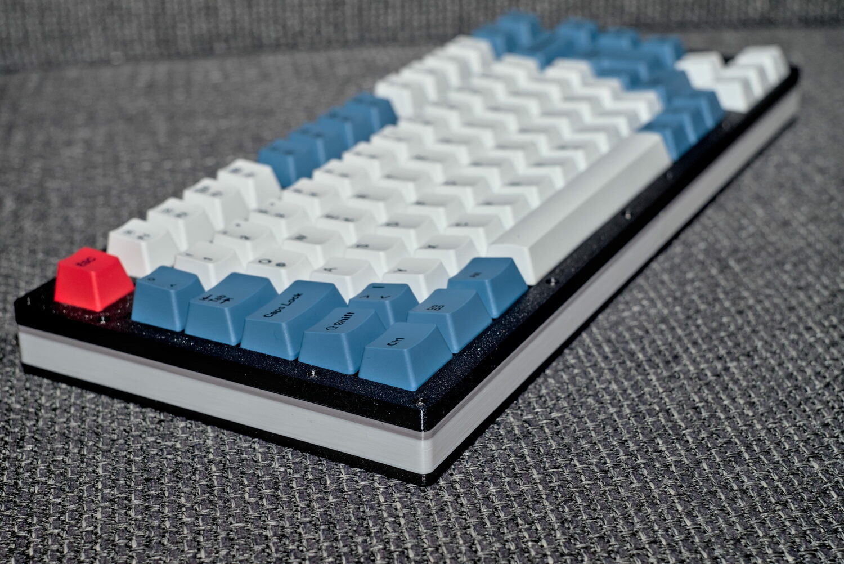
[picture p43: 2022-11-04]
pics/pics/andimoto75Q1iso-004.jpg

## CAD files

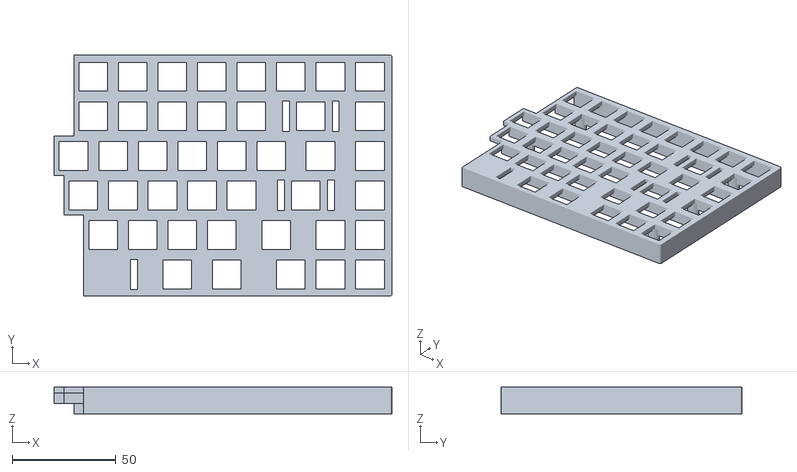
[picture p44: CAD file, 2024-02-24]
stl/andimoto7583/andimoto7583-obj-cnc/Unnamed-andimoto7583_mainCaseRight.obj
162.9 x 116.3 x 13.0

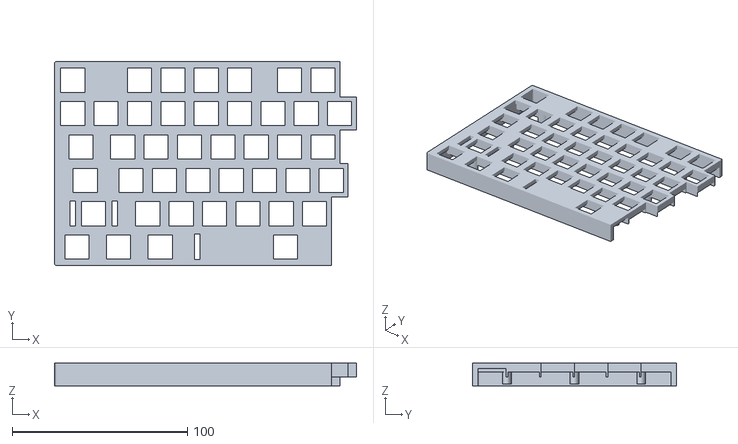
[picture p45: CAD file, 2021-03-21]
stl/andimotoSmallTKL/andimotoSmallTKL_mainCaseLeft.stl
172.4 x 116.3 x 13.0

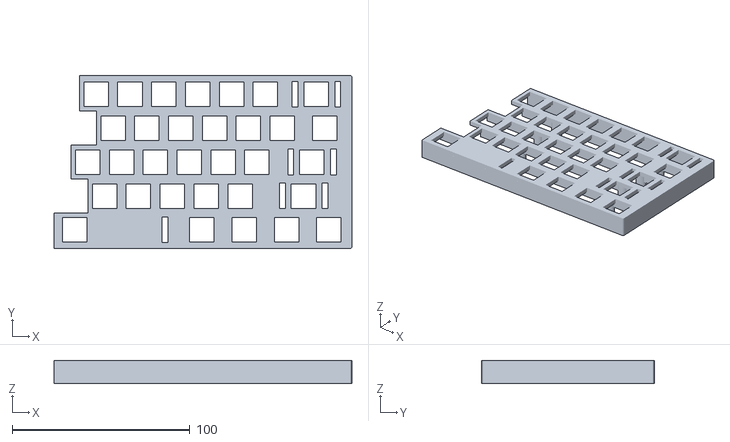
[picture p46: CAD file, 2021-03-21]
stl/andimoto6061/andimoto6061_mainCaseRight.stl
167.7 x 97.2 x 13.0

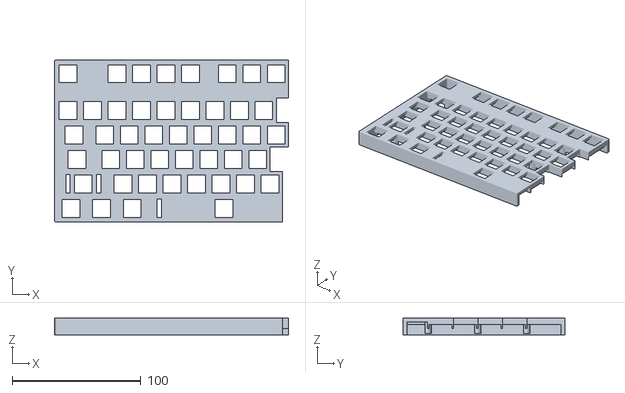
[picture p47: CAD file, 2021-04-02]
stl/andimotoTKL/andimotoTKL_mainCaseLeft.stl
182.0 x 125.8 x 13.0

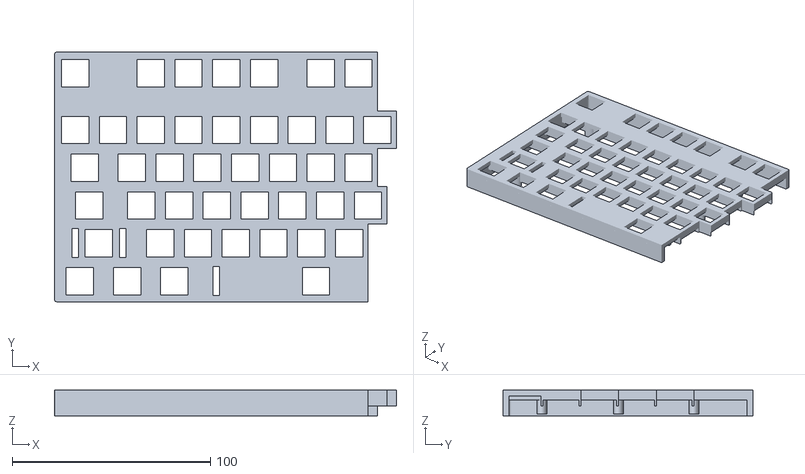
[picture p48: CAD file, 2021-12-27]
stl/andimotoSmallTKL/andimotoSmallTKL_fRow/andimotoSmallTKL_fRow_mainCaseLeft_Teensy2.stl
172.4 x 125.8 x 13.0

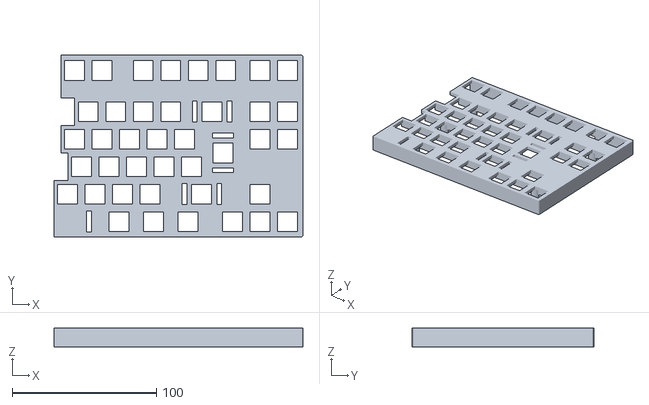
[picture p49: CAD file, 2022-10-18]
stl/andimotoSmallTKLiso/andimotoSmallTKLiso_mainCaseRight-ProMicro.stl
172.4 x 125.8 x 13.0

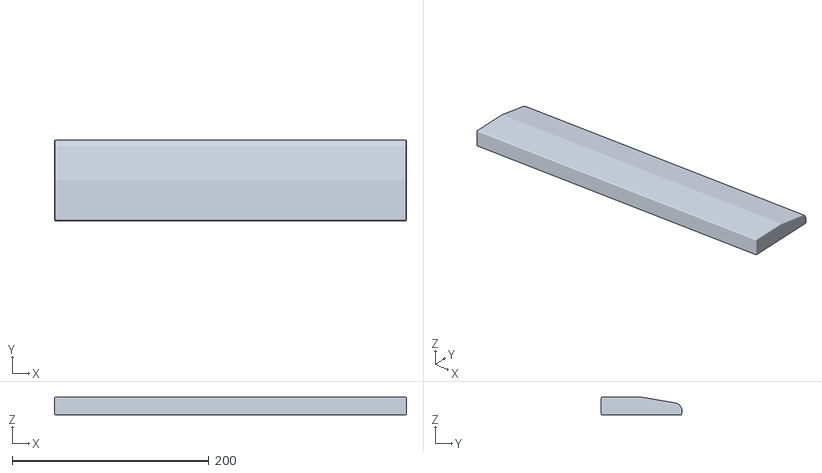
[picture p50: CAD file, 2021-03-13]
stl/andimotoTKLiso/wrist/wrist358Complete.stl
358.0 x 82.0 x 18.0

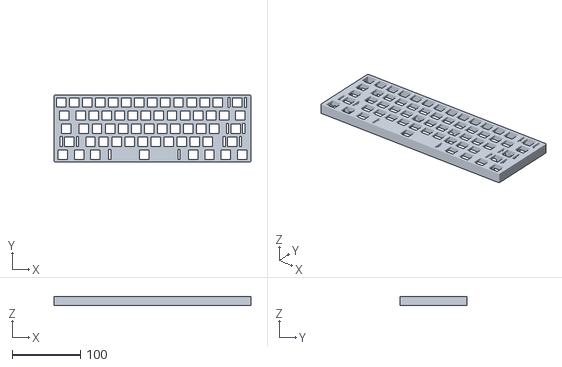
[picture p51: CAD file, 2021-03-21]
stl/andimoto6061/andimoto6061_mainCase.stl
287.8 x 97.2 x 13.0

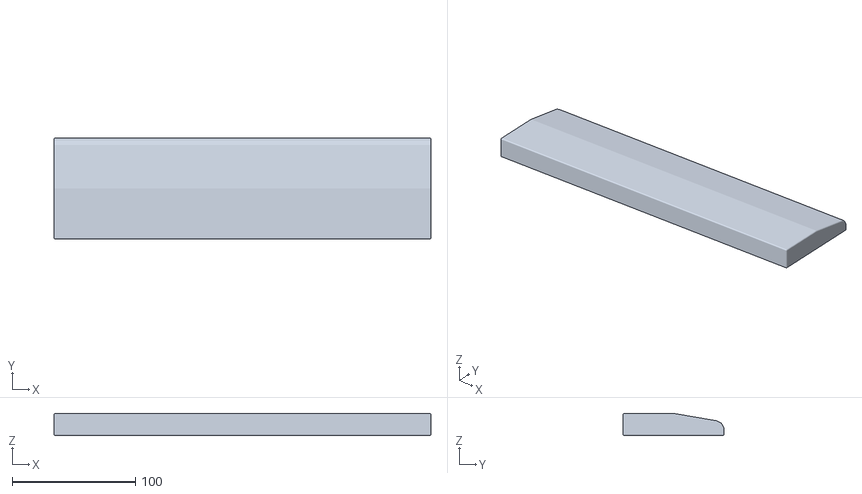
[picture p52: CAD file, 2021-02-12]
stl/andimoto7583/wrist/wrist306Complete.stl
306.0 x 82.0 x 18.0

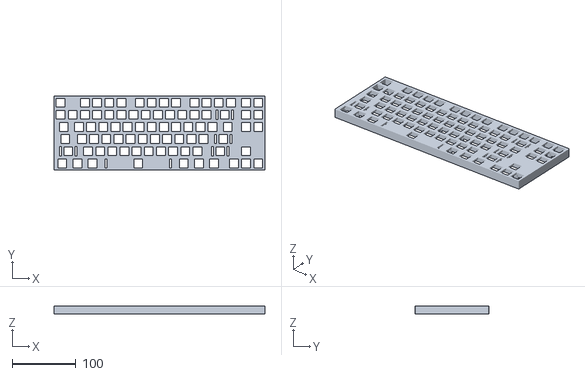
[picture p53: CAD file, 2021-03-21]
stl/andimotoSmallTKL/andimotoSmallTKL_mainCase.stl
330.6 x 116.3 x 13.0

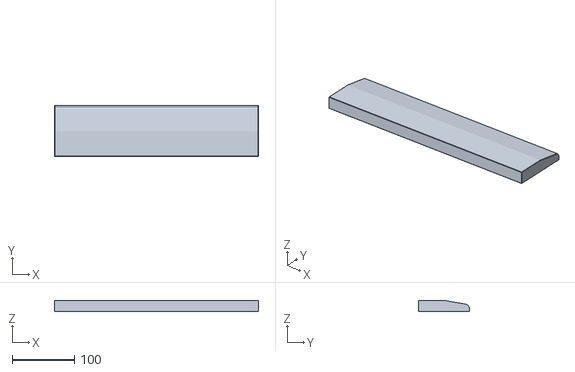
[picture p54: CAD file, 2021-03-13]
stl/andimotoSmallTKLiso/wristRest/wrist330_complete.stl
329.0 x 82.0 x 18.0

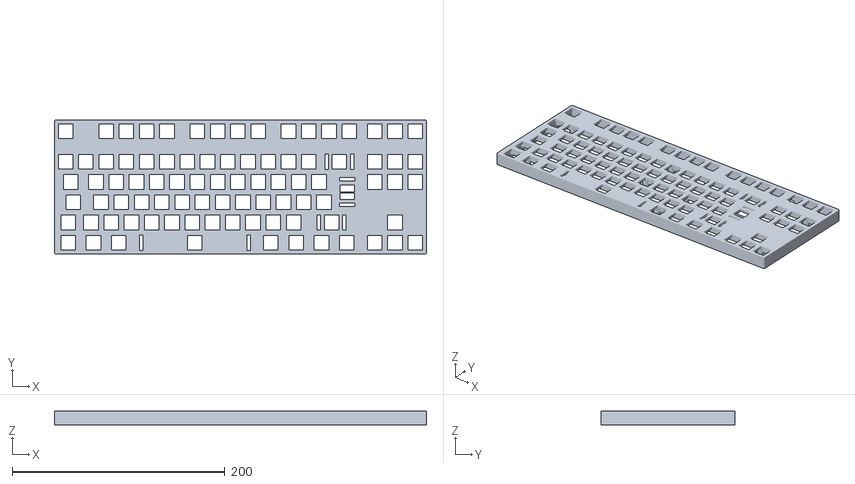
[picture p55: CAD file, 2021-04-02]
stl/andimotoTKLiso/andimotoTKLiso_mainCase.stl
349.7 x 125.8 x 13.0

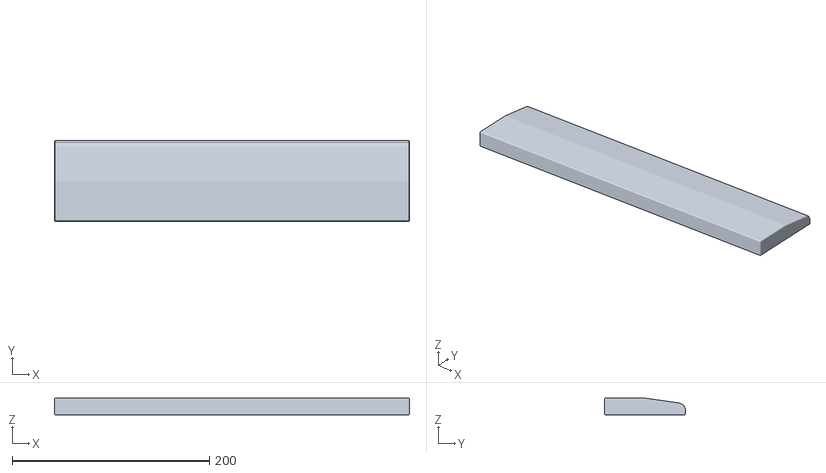
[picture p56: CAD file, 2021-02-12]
stl/wrist36complete.stl
360.0 x 82.0 x 17.0

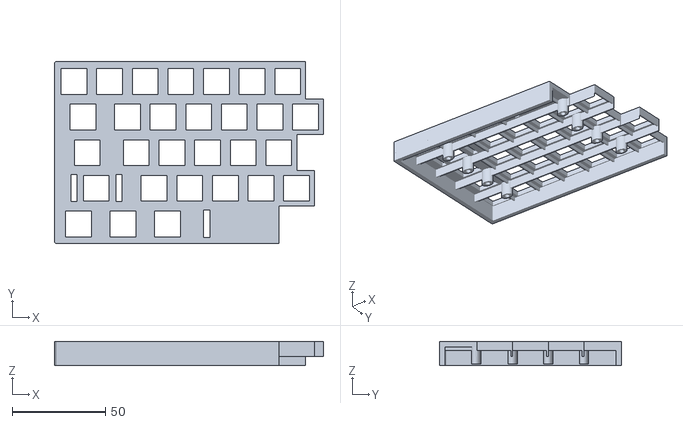
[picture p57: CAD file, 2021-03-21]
stl/andimoto6061/andimoto6061_mainCaseLeft.stl
143.9 x 97.2 x 13.0

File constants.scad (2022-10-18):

/* constants.scad
Author: andimoto@posteo.de
----------------------------
for placing assambled parts and
single parts go to end of this file

this file is a template which may be copied to create a new keyboard layout
and to configure and place essential parts like usb cut out, screw holes or stabilizers

this file includes KeyV2 files. see https://github.com/rsheldiii/KeyV2
if you don't want this file to be included, just don't clone this library or
remove the call for placing all keycaps on the keyboard.
*/


/* ###### don't touch this! ###### */
//Unit square length, from Cherry MX data sheet
//this is the size of 1unit including keycap size and
//the space to the next keycap
lkey=19.05;
//Hole size, from Cherry MX data sheet
holesize=14;

//calculated vars
holediff=lkey-holesize;
caseWidth=width*lkey;
caseDepth=height*lkey;

/* for costar style stab cutouts */
stabX=3.3;//6.75;
stabCutoutWidth=0.825;

/* these are the values of the costar style stabilizers */
shortStabX=24;
longStabX=101;

innerExtraLid = 1;

//constant for inner case
innerCaseRadius=1;

//default height of the frame when in use
frameHeight = 6;

//height of the head of a cylinder head screw m2
screwHeadHeight = 3;

extraSpace=0.8;

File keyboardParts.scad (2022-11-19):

/* keyboardParts.scad
Author: andimoto@posteo.de
----------------------------
for placing assambled parts and
single parts go to end of this file

this file includes KeyV2 files. see https://github.com/rsheldiii/KeyV2
if you don't want this file to be included, just don't clone this library or
remove the call for placing all keycaps on the keyboard.
*/

include <../KeyV2/includes.scad>

/* variable for calculation */
cutLength = 0;
/* this variable  */
cutThrough = 5;

tempHeigth=caseHeight-plateThickness+extra;

function getExtraFRow(extraFRow=false) = (extraFRow==true) ? lkey*0.5 : 0 ;
function getSkirtY() = (skirtSelect==true) ? skirtY : 0 ;
function getSkirtX() = (skirtSelect==true) ? skirtX : 0 ;
function getHalf(yPosKey) = (yPosKey % 1);

module switchhole(){
	union(){
		translate([0,0,-extra/2-cutThrough])
		cube([holesize+switchHoleTolerance,holesize+switchHoleTolerance,plateThickness+cutThrough+extra]);
	}
}

module costarStabilizer(){
	union(){
		translate([-stabX/2,0,-0.8])
		cube([stabX,holesize+1,plateThickness/*+extra*/]);
		translate([-stabX/2,0.25,plateThickness-0.8])
		cube([stabX,holesize+0.5,1+extra]);
		/* debug point */
		/* #cylinder(r=0.1,h=10); */
	}
}
/* costarStabilizer(); */

costarStabYdelta = -0.5;
module holematrix(holes,startx,starty,zCase){

	/* create extra objects to be cutout like isoEnter, etc. */
	extraCutoutHook();

	for (key = holes){
		/* echo (key[0][0],key[0][1],key[1]); */
		/* place switch holes */
		if(key[1] >= 1){
			half = getHalf(key[0][1]);// % 1;
			if(half == 0.5){
				/* all switchholes which have vertical sized keycaps like numpad-enter or numpad+ */
				translate([startx+lkey*key[0][0], starty-lkey*key[0][1], zCase-extra])
				translate([(lkey*key[1]-holesize)/2,(lkey - holesize)/2, 0])
				switchhole();

				if(enableStabsOnHalfs == true)
				{
					/* directly add costarStabilizers to this switchhole */
					translate([19.3,-5,0])
					translate([startx+lkey*key[0][0], starty-lkey*key[0][1], zCase-extra])
					translate([(lkey*key[1]-holesize)/2+(holesize/2)-shortStabX/2,(lkey - holesize)/2+costarStabYdelta+0.5, 0])
					rotate([0,0,90]) costarStabilizer();

					translate([-4.7,20,0])
					translate([startx+lkey*key[0][0], starty-lkey*key[0][1], zCase-extra])
					translate([(lkey*key[1]+holesize)/2-(holesize/2)+shortStabX/2,(lkey - holesize)/2+costarStabYdelta-0.5, 0])
					rotate([0,0,90]) costarStabilizer();
				}
			}
			else
			{
				if((key[0][1]==0) && (fRowSeparator==true))
				{
					translate([startx+lkey*key[0][0], starty-lkey*(key[0][1])+getExtraFRow(fRowSeparator), zCase-extra])
					translate([(lkey*key[1]-holesize)/2,(lkey - holesize)/2, 0])
					switchhole();
				}
				else
				{
					translate([startx+lkey*key[0][0], starty-lkey*key[0][1], zCase-extra])
					translate([(lkey*key[1]-holesize)/2,(lkey - holesize)/2, 0])
					switchhole();
				}
			}
		}

		/* place switch holes - end */

		/* debugging - remove comment to show root point of holesize */
		/* translate([startx+lkey*key[0][0], starty-lkey*key[0][1], zCase-extra])
		translate([(lkey*key[1]-holesize)/2,(lkey - holesize)/2, 0])
		#cylinder(r=0.1,h=10); */

		/* place stabilizers */
		if (key[1]>1.75){
			temp=lkey*key[1];
			/* echo("Stab! ", temp); */

			if(key[1]>6)
			{
				/* stabilizers for spacebar */
				translate([startx+lkey*key[0][0], starty-lkey*key[0][1], zCase-extra])
				translate([(lkey*key[1]-holesize)/2+(holesize/2)-longStabX/2,(lkey - holesize)/2+costarStabYdelta, 0])
				costarStabilizer();

				translate([startx+lkey*key[0][0], starty-lkey*key[0][1], zCase-extra])
				translate([(lkey*key[1]+holesize)/2-(holesize/2)+longStabX/2,(lkey - holesize)/2+costarStabYdelta, 0])
				costarStabilizer();
			}
			else
			{
				/* other stabilizers than spacebar */
				translate([startx+lkey*key[0][0], starty-lkey*key[0][1], zCase-extra])
				translate([(lkey*key[1]-holesize)/2+(holesize/2)-shortStabX/2,(lkey - holesize)/2+costarStabYdelta, 0])
				costarStabilizer();

				translate([startx+lkey*key[0][0], starty-lkey*key[0][1], zCase-extra])
				translate([(lkey*key[1]+holesize)/2-(holesize/2)+shortStabX/2,(lkey - holesize)/2+costarStabYdelta, 0])
				costarStabilizer();
			}
		}

	}
}

module keycapSpace(factor=1)
{
	union(){
		translate([-extraSpace/2,-extraSpace/2,0])
		cube([lkey*factor+extraSpace,lkey+extraSpace,plateThickness+cutThrough+extra]);
	}
}

module keycapMatrix(holes,startx,starty,zCase)
{
	extraKeycapCutoutHook();
	for (key = holes){
		/* echo (key[0][0],key[0][1],key[1]); */
		/* place switch holes */
		if(key[1] >= 1){
			half = getHalf(key[0][1]);// % 1;
			if(half == 0.5){
				/* all switchholes which have vertical sized keycaps like numpad-enter or numpad+ */
				translate([startx+lkey*key[0][0], starty-lkey*key[0][1], zCase-extra])
				translate([(lkey*key[1]-holesize)/2,(lkey - holesize)/2, 0])
				scale([1,1,key[1]]) keycapSpace(); /*todo: test this with numpad!!*/
			}
			else
			{
				if((key[0][1]==0) && (fRowSeparator==true))
				{
					translate([startx+lkey*key[0][0], starty-lkey*(key[0][1])+getExtraFRow(fRowSeparator), 0])
					keycapSpace(key[1]);
				}
				else
				{
					translate([startx+lkey*key[0][0], starty-lkey*key[0][1], 0])
					keycapSpace(key[1]);
				}
			}
		}
	}
}

module capFrameScrewHoles(screwRad,screwLen,noSupport=true)
{
	if(frameScrewsEnable == true)
	{
		for(hole = frameScrewHoleArray)
		{
			translate([hole[0],hole[1],0])
			union()
			{
				if(noSupport == true)
				{
					difference() {
						translate([0,0,-0.2]) cylinder(r=screwRad,h=0.2);
						translate([screwRad/2,-screwRad,-0.2]) cube([screwRad,screwRad*2,0.2]);
						translate([-(screwRad+screwRad/2),-screwRad,-0.2]) cube([screwRad,screwRad*2,0.2]);
					}
				}
				cylinder(r=screwRad,h=screwLen+extra);
			}
		}
	}
}

/* translate([0,0,30]) capFrameScrewHoles(2.1,3,true); */

module capFrame(capLayout)
{
	color(frameColor)
	difference()
	{
		/* 6mm is the height of the plate to the keycap usally */
		outerCase(h=frameHeight);
		translate([0,0,-extra]) keycapMatrix(capLayout,0,caseDepth-lkey,tempHeigth);

		capFrameScrewHoles(screwRad=1.1,screwLen=frameHeight,noSupport=false);
		translate([0,0,3]) capFrameScrewHoles(screwRad=2.1,screwLen=screwHeadHeight);
	}

}

module capFrameR(capLayout)
{
	difference() {
		capFrame(capLayout);

		separatorCubeX = width*lkey+innerCaseRadius*2+skirtX*2;
		separatorCubeY = height*lkey+getExtraFRow(fRowSeparator)+innerCaseRadius*2+skirtY*2;
		translate([-innerCaseRadius-skirtX,-innerCaseRadius-skirtY,0])
			cube([separatorCubeX/2, separatorCubeY, frameHeight]);
	}
}

module capFrameL(capLayout)
{
	difference() {
		capFrame(capLayout);

		separatorCubeX = width*lkey+innerCaseRadius*2+skirtX*2;
		separatorCubeY = height*lkey+getExtraFRow(fRowSeparator)+innerCaseRadius*2+skirtY*2;
		translate([separatorCubeX/2,0,0])
		translate([-innerCaseRadius-skirtX,-innerCaseRadius-skirtY,0])
			cube([separatorCubeX/2, separatorCubeY, frameHeight]);
	}
}

module caseStabilizer(w,h,holes,startx,starty,zCase)
{
	for (key = holes){
		/* don't place case stabilizer on iso enter button */
		half = getHalf(key[0][1]);
		/* echo(half); */
		/* place horizontal case stabilizer under the corresponding switchhole,
		but only if switch placement is a integer number (no rest of modulo) and
		not on the 1st row (key[0][1]==0 ) because this places the caseStabilizer inside
		the case wall and ruins color simulation*/
		if(key[0][1]!=2.5 && key[0][1] != 0 && half == 0){
			translate([0,lkey*key[0][1]-1+caseStabMov,innerCaseSpace])
			cube([w,1,caseHeight-plateThickness-innerCaseSpace]);
		}
	}

	for (key = holes){
		if((key[0][1]==0) && (fRowSeparator==true))
		{
			/* don't place case stabilizer on iso enter button */
			translate([startx+lkey*key[0][0]+lkey*key[1]-innerCaseRadius,starty-lkey*key[0][1],caseHeight-plateThickness-2])
			cube([1,lkey+getExtraFRow(fRowSeparator),2]);
		}

		if(key[0][1]!=2.5){
			/* don't place case stabilizer on iso enter button */
			translate([startx+lkey*key[0][0]+lkey*key[1]-1,starty-lkey*key[0][1],caseHeight-plateThickness-2])
			cube([1,lkey,2]);
		}

		/*put some extra stabilizer profiles to spacebar*/
		if(key[1]>6)
		{
			translate([startx+lkey*key[0][0]+lkey*key[1]/3,starty-lkey*key[0][1],caseHeight-plateThickness-2])
			cube([1,lkey,2]);
			translate([startx+lkey*key[0][0]+lkey*key[1]/1.5,starty-lkey*key[0][1],caseHeight-plateThickness-2])
			cube([1,lkey,2]);
		}
	}
}


switchSimArray = [
[0,0],
[holesize,0],
[holesize-holesize/4,holesize/2],
[holesize-3*holesize/4,holesize/2]];
module switchSim()
{
	translate([-7,-7,0]) union()
	{
		color(switchColorTop) translate([0,10.5,0])
			rotate([90,0,0]) linear_extrude(7) polygon(switchSimArray);
		color(switchColorTop) translate([3.5,0,0])
			rotate([90,0,90]) linear_extrude(7) polygon(switchSimArray);
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

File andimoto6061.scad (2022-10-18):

/* andimoto6061.scad
Author: andimoto@posteo.de
----------------------------
for placing assambled parts and
single parts go to end of this file

this file is a template which may be copied to create a new keyboard layout
and to configure and place essential parts like usb cut out, screw holes or stabilizers

this file includes KeyV2 files. see https://github.com/rsheldiii/KeyV2
if you don't want this file to be included, just don't clone this library or
set the 'DoKeycapSimulation' parameter of KeyboardSim() to false.
*/

/* ########## predefinitions ############ */
$fn=30;


/* Thickness of entire plate which holds the switches.
 * this is the top of the keyboard
 */
plateThickness=3;
/* thickness of the walls */
wallThickness=3;
/* height of the case */
caseHeight=13;

/* space between inner case stabilizers
   and the bottom/lip of the case */
innerCaseSpace = 5;

//length, in units, of board
width=15;
//Height, in units, of board
height=5;

/* thickness of the lid.
   the function 'lid()' will add an
	 extra mm to get a step for the lip
	 see 'innerExtraLid' variable in constants  */
lidThickness=3;


/* ########## variables for cutting keyboard into smaller pieces ########## */
/* these are unit values; one unit is one key or switchhole
 * this makes the keyboard printable on nearly every printer.
 */
cutAfterUnits = 6.5;
spacebarCut = 2.5;

/* fRowSeparator [true/false]
 * Select separation of F-Row (or Row 0; key[0][1]=0)
 * This will move the upper row by a half unit (lkey*0.5)
 */
fRowSeparator=false;

/* skirt selctor and skirt settings
 * select 'skirtSelect' as true to activate a additional skirt
 * around the keyboard case. The variables 'skirtX' & 'skirtY'
 * are configurable as you want the skirt. These values ADD the
 * configured amount to the side of the case.
 * Note: be careful here, this interacts with caseRadius
 *
 * If this is activated you can call 'capFrame()'
 * (or capFrameR/capFrameL) to create a nice frame
 * around the keycaps to cover the switches. This may give
 * a cleaner look if this is prefered.
 */
skirtSelect = false;
skirtX = 0;
skirtY = 0;

/* enables screw holes in frame (if capFrame() is called)
   and in the case. The screws will be placed according to
   the array frameScrewHoleArray[] around the case and frame.
   */
frameScrewsEnable = false;

/* edge radius of the case
 * Note: be careful here, this interacts with skirtX/Y
 * THIS IS ONLY VALID WHEN 'skirtSelect' IS TRUE
 */
caseRadius=10;


/* ################## calculated vars #################### */


/* debug extra for avoiding artefacts @ compilation */
extra=1;


/* add or reduce some tolerance for the switch holes.
 * depends on your printers resolution and if you want
 * narrow or loose fit of switches. do not configure to
 * narrow switch holes. when placing switches into the holes
 * they will pull the case apart and bend it. this will normally
 * be reduced by the lid, but do not overact this.
 */
switchHoleTolerance = -0.2;


/* ############################################## */
/* ########## LAYOUT AND KEYCAP COLORS ########## */
/* ############################################## */
/* Usage: [[column place, row place],keycap unit, color for keycap simulation] */
/* 				"column place" is the place of the switch hole in the column;
 					- example: Esc, F1, F2, F3, ...
					            0    1   2   3  ...
					"row place" is the place of the switch in the row;
					- example:  Esc, accent, TAB, CapsLock, ...
*/

/* ansiUS_6061 */
layout = [
//start ROW 1
[[0,0],1,"White"], //'
[[1,0],1,"MintCream"], //1
[[2,0],1,"MintCream"], //2
[[3,0],1,"MintCream"], //3
[[4,0],1,"MintCream"], //4
[[5,0],1,"MintCream"], //5
[[6,0],1,"MintCream"], //6
[[7,0],1,"MintCream"], //7
[[8,0],1,"MintCream"], //8
[[9,0],1,"MintCream"], //9
[[10,0],1,"MintCream"], //0
[[11,0],1,"MintCream"], //-_
[[12,0],1,"MintCream"], //=+
[[13,0],2,"White"], //backspace
//start ROW 2
[[  0,1],1.5,"Grey"], //TAB
[[1.5,1],1,"MintCream"], //Q
[[2.5,1],1,"MintCream"], //W
[[3.5,1],1,"MintCream"], //E
[[4.5,1],1,"MintCream"], //R
[[5.5,1],1,"MintCream"], //T
[[6.5,1],1,"MintCream"], //Y
[[7.5,1],1,"MintCream"], //U
[[8.5,1],1,"MintCream"], //I
[[9.5,1],1,"MintCream"], //O
[[10.5,1],1,"MintCream"], //P
[[11.5,1],1,"MintCream"], //[
[[12.5,1],1,"MintCream"], //]
[[13.5,1],1.5,"Grey"], // \
//start ROW 3
[[    0,2],1.75,"Grey"], //CapsLock
[[ 1.75,2],1,"MintCream"], //A
[[ 2.75,2],1,"MintCream"], //S
[[ 3.75,2],1,"MintCream"], //D
[[ 4.75,2],1,"MintCream"], //F
[[ 5.75,2],1,"MintCream"], //G
[[ 6.75,2],1,"MintCream"], //H
[[ 7.75,2],1,"MintCream"], //J
[[ 8.75,2],1,"MintCream"], //K
[[ 9.75,2],1,"MintCream"], //L
[[10.75,2],1,"MintCream"], //;
[[11.75,2],1,"MintCream"], //'
[[12.75,2],2.25,"Grey"], //ENTER
//start ROW 4
[[    0,3],2.25,"Grey"], //LShift
[[ 2.25,3],1,"MintCream"], //Z
[[ 3.25,3],1,"MintCream"], //X
[[ 4.25,3],1,"MintCream"], //C
[[ 5.25,3],1,"MintCream"], //V
[[ 6.25,3],1,"MintCream"], //B
[[ 7.25,3],1,"MintCream"], //N
[[ 8.25,3],1,"MintCream"], //M
[[ 9.25,3],1,"MintCream"], //,
[[10.25,3],1,"MintCream"], //.
[[11.25,3],1,"MintCream"], // /
[[12.25,3],2.75,"Grey"], //RShift
//start ROW 5
[[   0,4],1.25,"Grey"], //LCTRL
[[1.25,4],1.25,"Grey"], //TUX
[[2.5 ,4],1.25,"Grey"], //ALT
[[3.75,4],6.25,"White"], //SPACE
[[10  ,4],1.25,"Grey"], //COMP
[[11.25,4],1.25,"Grey"], //Fn
[[12.5 ,4],1.25,"Grey"], //RCTRL
[[13.75 ,4],1.25,"Grey"], //RCTRL

];

/* enable placment of stabilizers on switchholes with x.5 unit in y direction
 * for example: true for numpad enter or numpad +
 * if you just want a single unit (1unit keycap) you can set this to false */
enableStabsOnHalfs = true;

/* move pcb and usb cutout in x direction
   for better placement */
pcbShift=0;

/* cutout for micro usb plug (not the housing of the usb plug!)
 * change this if using mini usb
 */
usbCutX=8;
usbCutY=wallThickness;

/* Arduino Pro Micro USB Port height */
usbCutZ=3.4;

/* Teensy2 USB Port height */
/* usbCutZ=4.5; */

/* space in lid for placing the controller pcb.
 * this example is for arduino pro micro clones.
 * if you use teensy2.0 or something else configure
 * the size of the controller pcb you use. the function
 * 'pcbCutout()' will add 1mm to 'pcbWidth' for some clearance.
 * pcbLength should be as exactly as possible. this keeps the pcb
 * perfectly even if pcbWidth is to much
 */
 /* teensy2 cutout */
 pcbHeight = 1.8;
 pcbWidth = 18.5;
 pcbLength = 31.4;

 /* arduino pro micro cutout */
 //pcbHeight = 2;
 //pcbWidth = 18;
 //pcbLength = 34;

/* set 'addRisers' to true or false
 * to calculate a lid with holes for risers
 * and add risers to simulation
 */
addRisers = true;

/* keyboardRiser config
 * angleBaseX -> width of the riser
 * angleBaseY -> depth of the riser
 */
angleBaseY=80;
angleBaseX=60;
/* riser edge radius */
angleBaseRad=1;
/* polygon; this is the shape of the riser */
riserPoints = [
[0,0],
[angleBaseY,0],
[angleBaseY,3],
[0,16]
];

/* optional: move keyboard risers as needed */
xRiserR=0;
xRiserL=0;
yRiserAll=0;

riserConnectorRadius = 5;
riserConnectorX = 0;
riserConnectorY1 = 50;




/* ####### include keyboard lib ############ */
include <constants.scad>
include <keyboardParts.scad>

/* this module gets called in 'holematrix' and adds a specific
 * object to the 'holematrix'. it enables placing switchholes
  * or other cutout objects to the model */
module extraCutoutHook()
{
}

/* this module gets called in 'keycapMatrix()' and adds a specific
 * object to the keycapMatrix. keycapMatrix is needed as a cutout element
 * from the frame. this hook gives possibility to add more elements such
 * as the enter keycap.
 */
module extraKeycapCutoutHook()
{
}

/* this module gets called in 'keySim()' and adds a specific
 * object to the 'key simulation'. it enables placing keys
  * or other objects to the model simulation */
module extraKeySimHook()
{
}


/* ####### screw hole config ######## */
/* set the screw holes to a good position.
 * if your keyboard is bigger, you can add some
 * more screw holes into the keyboard case and lid.
 */
screwHoleArray = [
[26,lkey-0.5], //left lower row
[114,lkey-0.5],
[170,lkey-0.5],
[260,lkey-0.5], // right lower row

[26,lkey*2+wallThickness-3], //left upper row
[110,lkey*2+wallThickness-3],
[171,lkey*2+wallThickness-3],
[256,lkey*2+wallThickness-3], //right upper row

[26,lkey*3+wallThickness-3], //left upper row
[110,lkey*3+wallThickness-3],
[171,lkey*3+wallThickness-3],
[256,lkey*3+wallThickness-3], //right upper row

[26,lkey*4+wallThickness-3], //left upper row
[114,lkey*4+wallThickness-3],
[171,lkey*4+wallThickness-3],
[256,lkey*4+wallThickness-3], //right upper row
];

/* rotate screw hole spacers */
screwSpacerRotation=0;

/* move horizontal case stabilizers inside the case.
 * to move horizontal by lkey/2 for half switch cutout.
 * this enables to set x.5 values in layout array.
 * else use 0!!
 */
caseStabMov=0;
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

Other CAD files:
stl/andimoto7583/andimoto7583-obj-cnc/Unnamed-andimoto7583_mainCaseLeft.obj
stl/andimoto7583/andimoto7583_mainCaseLeft.stl
stl/andimotoSmallTKL/andimotoSmallTKL_fRow/andimotoSmallTKL_fRow_mainCaseRight_Teensy2.stl
andimoto6064.scad
andimoto7583.scad
andimoto75Q1-iso.scad
andimoto75Q1.scad
andimotoSmallTKL.scad
andimotoSmallTKLiso.scad
andimotoTKL.scad
andimotoTKLiso.scad
deprecated/75erKeyboard.scad
keebCase.scad
macropad.scad
numpad.scad
stl/andimoto6061/andimoto6061_keyboardRiser.stl
stl/andimoto6061/andimoto6061_lid.stl
stl/andimoto6061/andimoto6061_lidL.stl
stl/andimoto6061/andimoto6061_lidR.stl
stl/andimoto6064/andimoto6064_keyboardRiser.stl
stl/andimoto6064/andimoto6064_lid.stl
stl/andimoto6064/andimoto6064_lidL.stl
stl/andimoto6064/andimoto6064_lidR.stl
stl/andimoto6064/andimoto6064_mainCase.stl
stl/andimoto6064/andimoto6064_mainCaseLeft.stl
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

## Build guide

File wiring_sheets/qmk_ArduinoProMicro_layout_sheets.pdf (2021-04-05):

ArduinoProMicro
ArduinoProMicro | Layout
Row Col | | 1 | 2 | 3 | 4 | 5 | 6 | 7 | 8 | 9 | 10 | 11 | 12 | 13 | 14
| Col [] Row [] | 0 | 1 | 2 | 3 | 4 | 5 | 6 | 7 | 8 | 9 | 10 | 11 | 12 | 13
1 | 0
2 | 1
3 | 2
4 | 3
5 | 4
6 | 5

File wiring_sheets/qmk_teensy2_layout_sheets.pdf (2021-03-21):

Tabelle1
Teensy 2 | Layout
Row Col | | 1 | 2 | 3 | 4 | 5 | 6 | 7 | 8 | 9 | 10 | 11 | 12 | 13 | 14 | 15 | 16 | 17 | 18
| Col [] Row [] | 0 | 1 | 2 | 3 | 4 | 5 | 6 | 7 | 8 | 9 | 10 | 11 | 12 | 13 | 14 | 15 | 16 | 17
1 | 0
2 | 1
3 | 2
4 | 3
5 | 4
6 | 5

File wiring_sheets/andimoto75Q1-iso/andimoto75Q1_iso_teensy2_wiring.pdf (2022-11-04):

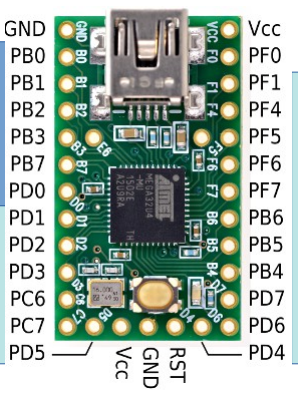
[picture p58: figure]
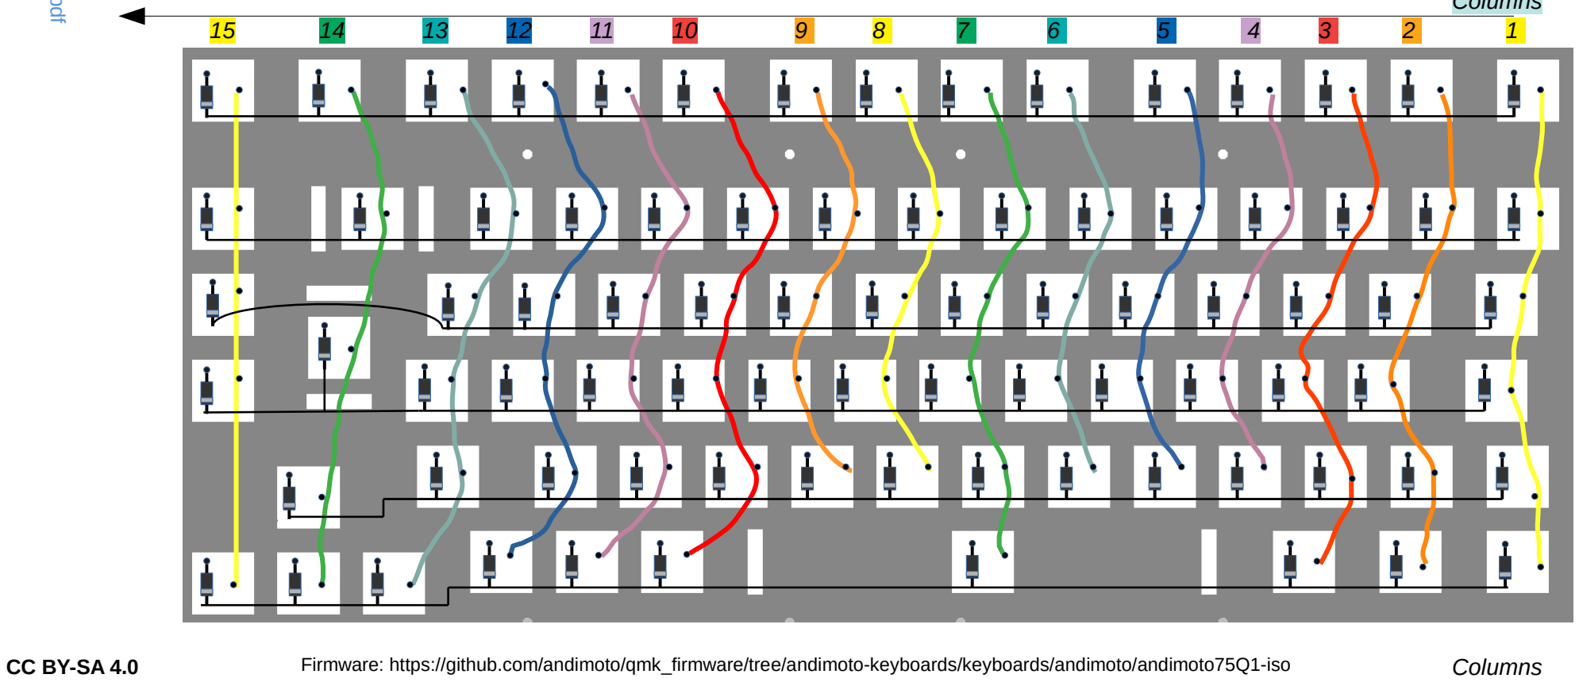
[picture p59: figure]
Columns; Firmware: https://github.com/andimoto/qmk_firmware/tree/andimoto-keyboards/keyboards/andimoto/andimoto75Q1-iso

15 | 14 | 13 | 12 | 11 | 10 | 9 | 8 | 7 | 6 | 5 | 4 | 3 | 2 | 1

https://www.pjrc.co

m/te
ensy/card

2
a_re

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
### Rows

### Columns

### Row 1 Row 2 Row 3 Row 4 Row 5 Row 6 Col 1 Col 2 Col 3 Col 4 Col 5 Col 6

### Col 17 Col 16 Col 15 Col 14 Col 13 Col 12 Col 11 Col 10 Col 9 Col 8 Col 7

# andimoto75Q1-iso wiring diagram

Note: As the Teensy 2.0 has enough pins available, I could do a direct wiring. This keyboard could also use a Arduino Pro Micro. The wiring of the smallTKL ANSI layout could be adopted for this ISO layout easily.

Wiring: Solder each line of „Rows“ and each line of „Columns“ to controller as described in diagram.

Set soldering iron to about 315°C. Also see wiring help from
QMK documentation. For connections directly to controller use thin wires. Otherwise there will be not enough space to close the case.
Note: Case diagram is mirrored!

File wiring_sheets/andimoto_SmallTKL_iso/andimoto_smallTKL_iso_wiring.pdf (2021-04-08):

17 | 16 | 15 | 14 | 13 | 12 | 11 | 10 | 9 | 8 | 7 | 6 | 5 | 4 | 3 | 2 | 1

https://www.pjrc.co

m/te
ensy/card

2
a_re

v
5
_w

e
b.p

df (https://www.pjrc.com/teensy/card2a_rev5_web.pdf)

1

2

3

4

5

6

### Rows

### Columns

### Columns

### Row 1 Row 2 Row 3 Row 4 Row 5 Row 6 Col 1 Col 2 Col 3 Col 4 Col 5 Col 6

### Col 17 Col 16 Col 15 Col 14 Col 13 Col 12 Col 11 Col 10 Col 9 Col 8 Col 7

# andimoto smallTKL iso wiring diagram

Note: This wiring is very wastful. As the Teensy 2.0 has enough pins available, I could do a direct wiring. This keyboard could also use a Arduino Pro Micro. The wiring of the smallTKL ANSI layout could be adopted for this ISO layout easily.

Wiring: Solder each line of „Rows“ and each line of „Columns“ to controller as described in diagram.

Set soldering iron to about 315°C. Also see wiring help from
QMK documentation. For connections directly to controller use thin wires. Otherwise the will be not much space to close the case.
Note: Case diagram is upside-down!
CC BY-SA 4.0 | Firmware: https://github.com/andimoto/qmk_firmware/tree/andimoto-keyboards/keyboards/andimoto/andimotoSmallTKLiso
17 | 16 | 15 | 14 | 13 | 12 | 11 | 10 | 9 | 8 | 7 | 6 | 5 | 4 | 3 | 2 | 1

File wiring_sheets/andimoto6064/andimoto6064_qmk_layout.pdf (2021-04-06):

andimoto6064
ArduinoProMicro | Layout andimoto6064
Row Col | | 1 | 2 | 3 | 4 | 5 | 6 | 7 | 8 | 9 | 10 | 11 | 12 | 13
| Col [] Row [] | 0 | 1 | 2 | 3 | 4 | 5 | 6 | 7 | 8 | 9 | 10 | 11 | 12
2 | 1 | Esc `/~ | 1 F1 | 2 F2 | 3 F3 | 4 F4 | 5 F5 | 6 F6 | 7 F7 | 8 F8 | 9 F9 | 0 F10 | Minus F11 | Equal F12
3 | 2 Tab | | Q | W | E | R | T | Y | U | I | O | P | [ | ]
4 | 3 | L-Shift/ Reset | A | S | D | F4 | G | H | J | K | L | ; | ' | Enter
5 | 4 L-Shift | | Z | X | C | V | B | N | M | , | . | / | R-Shift | Up
6 | 5 L-Ctrl | | LGUI / Win | Alt | Space | Fn (Mo) | App/ Context | Left | Down | Right | Del | \ | | BkSpc

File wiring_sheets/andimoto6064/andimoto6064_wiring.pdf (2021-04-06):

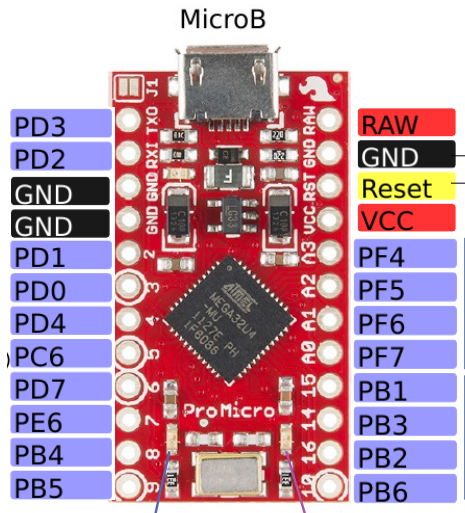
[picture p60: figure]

http://cdn.sp

arkfun.co

m/d

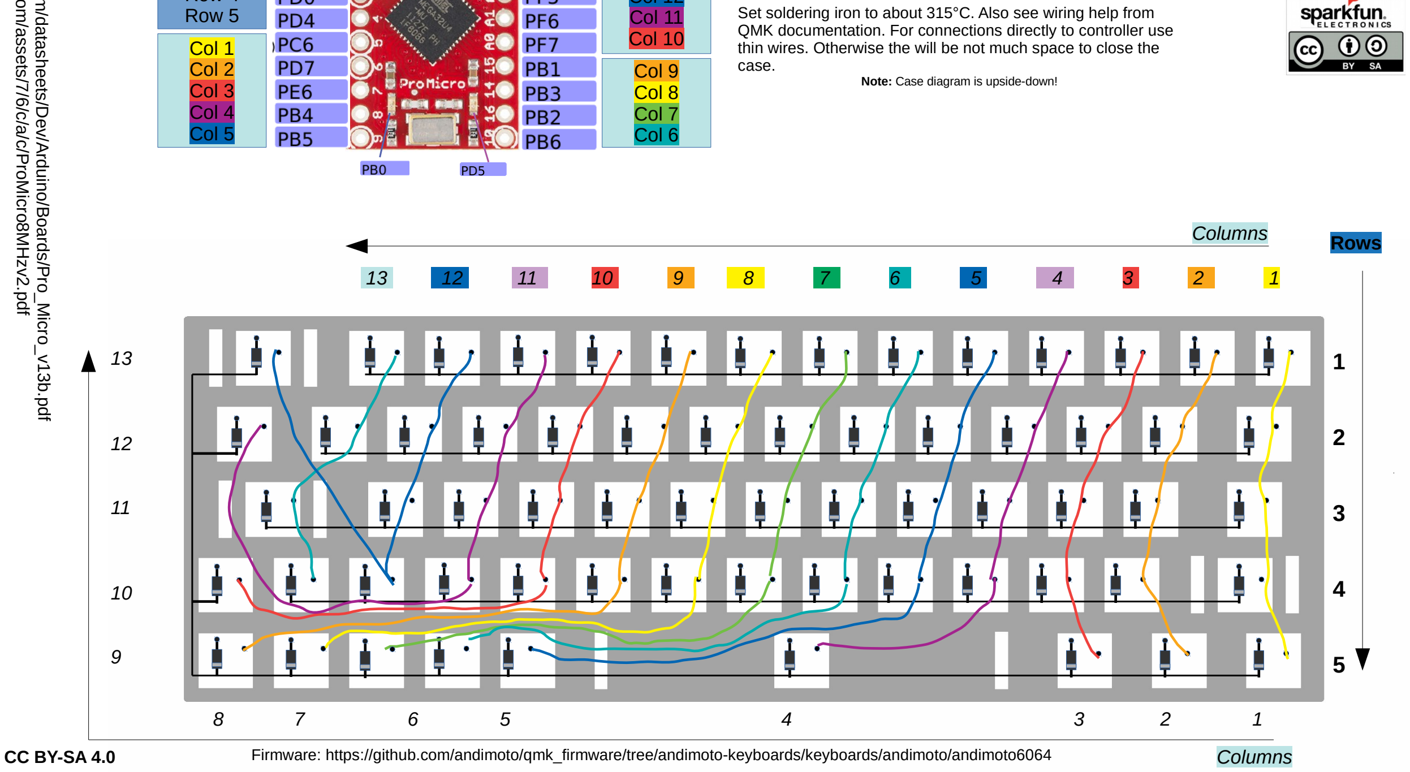
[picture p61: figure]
ets/D; e v/Arduino/B; o ards/Pro; _ Micro; m/assets/7/6/c/a/c/Pro; Micro; Hzv; Rows; Columns; Row 5 Col 1 Col 2 Col 3 Col 4 Col 5; Col 9 Col 8 Col 7 Col 6; Col 11 Col 10; case.; Note: Case diagram is upside-down!; Firmware: https://github.com/andimoto/qmk_firmware/tree/andimoto-keyboards/keyboards/andimoto/andimoto6064

atashe

https://cdn.sp

arkfun.co

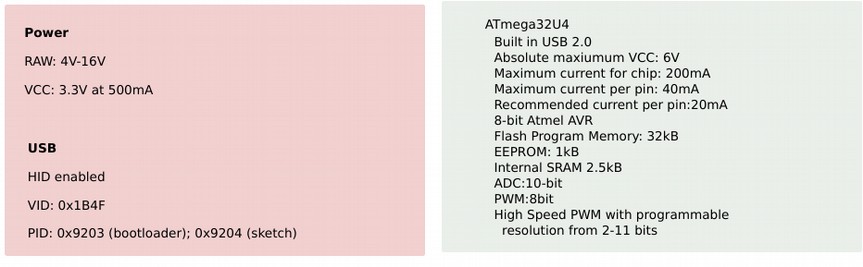
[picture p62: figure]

Parts of Controller Diagram taken from Sparkfun documentation

### Row 1 Row 2

### Row 3 Row 4

### Col 13 Col 12

Reset Switch

# andimoto6064 wiring diagram

Note: add a reset switch to set controller into bootloader mode for flashing qmk. This switch will be obsolete as
long qmk runs on controller as it is possible to reset the
keyboard with a shortcut.
Wiring: Solder each line of „Rows“ and each line of „Columns“ to controller as described in diagram.

Set soldering iron to about 315°C. Also see wiring help from
QMK documentation. For connections directly to controller use thin wires. Otherwise the will be not much space to close the

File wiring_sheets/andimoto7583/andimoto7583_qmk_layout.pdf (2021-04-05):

andimoto7583
ArduinoProMicro | Layout andimoto7583
Row Col | | 1 | 2 | 3 | 4 | 5 | 6 | 7 | 8 | 9 | 10 | 11 | 12 | 13 | 14
| Col [] Row [] | 0 | 1 | 2 | 3 | 4 | 5 | 6 | 7 | 8 | 9 | 10 | 11 | 12 | 13
1 | 0 Esc | | F1 | F2 | F3 | F4 | F5 | F6 | F7 | F8 | F9 | F10 | F11 | F12 | PrtScr
2 | 1 `/~ | | 1 | 2 | 3 | 4 | 5 | 6 | 7 | 8 | 9 | 0 | Minus | Equal | BckSpc
3 | 2 Tab | | Q | W | E | R | T | Y | U | I | O | P | [ | ] | \
4 | 3 | L-Shift (CpsLk) | A | S | D | F4 | G | H | J | K | L | ; | ' | Enter
5 | 4 L-Shift | | Z | X | C | V | B | N | M | , | . | / | R-Shift | Up | Pause
6 | 5 L-Ctrl | | LGUI / Win | Alt | Space | R-Alt | Fn (Mo) | Left | Down | Right | End | PgDown PgUp | | Home | Del

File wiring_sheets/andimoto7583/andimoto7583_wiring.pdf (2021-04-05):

14 | 13 | 12 | 11 | 10 | 9 | 8 | 7 | 6 | 5 | 4 | 3 | 2 | 1
9 | 8 | 7 | 6 | 5 | 4 | 3 | 2 | 1

14

13

12

11

10

14 |

http://cdn.sp

arkfun.co

m/d
atashe

ets/D

e
v/Arduino/B

o
ards/Pro

_
Micro

_v13

b.p

df

https://cdn.sp

arkfun.co

m/assets/7/6/c/a/c/Pro

Micro

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
### Rows

### Columns

### Columns

Parts of Controller Diagram taken from Sparkfun documentation

### Row 1 Row 2

### Row 3 Row 4 Row 5 Row 6

### Col 1 Col 2 Col 3 Col 4

### Col 10 Col 9 Col 8 Col 7

### Col 14 Col 13 Col 12 Col 11

Reset Switch

Col 5 | Col 6

Note: Remove Rx/Tx resistors and LEDs very carefully!! Use both pads of each resitor to solder Col5 and Col 6 to it (and get more stability out of both pads). Do not use upper pad of LEDs as they hold VCC.

# andimoto7583 wiring diagram

Note: add a reset switch to set controller into bootloader mode for flashing qmk. This switch will be obsolete as
long qmk runs on controller as it is possible to reset the
keyboard with a shortcut.
Wiring: Solder each line of „Rows“ and each line of „Columns“ to controller as described in diagram. Arduino Pro Micro (Clones) are cheap but normally 2 pins are missing. Therefore Rx/Tx Resistors and LED should be removed. Then it is possible to place 84 switches max.

Set soldering iron to about 315°C. Also see wiring help from QMK documentation. For connections directly to controller use thin wires. Otherwise the will be not much space to close the case.
Note: Case diagram is upside-down!
CC BY-SA 4.0 | Firmware: https://github.com/andimoto/qmk_firmware/tree/andimoto-keyboards/keyboards/andimoto/andimoto7583

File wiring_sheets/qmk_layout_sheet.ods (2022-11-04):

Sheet: Teensy2
 | Teensy 2 |  |  |  |  | Layout
Row | Col | 1 | 2 | 3 | 4 | 5 | 6 | 7 | 8 | 9 | 10 | 11 | 12 | 13 | 14 | 15 | 16 | 17 | 18
 | Col [] Row [] | 0 | 1 | 2 | 3 | 4 | 5 | 6 | 7 | 8 | 9 | 10 | 11 | 12 | 13 | 14 | 15 | 16 | 17
1 | 0
2 | 1
3 | 2
4 | 3
5 | 4
6 | 5

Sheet: ArduinoProMicro
 | ArduinoProMicro |  |  |  |  |  |  |  | Layout
Row | Col | 1 | 2 | 3 | 4 | 5 | 6 | 7 | 8 | 9 | 10 | 11 | 12 | 13 | 14
 | Col [] Row [] | 0 | 1 | 2 | 3 | 4 | 5 | 6 | 7 | 8 | 9 | 10 | 11 | 12 | 13
1 | 0
2 | 1
3 | 2
4 | 3
5 | 4
6 | 5

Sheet: andimoto7583
 | ArduinoProMicro |  |  |  |  |  |  |  | Layout | andimoto7583
Row | Col | 1 | 2 | 3 | 4 | 5 | 6 | 7 | 8 | 9 | 10 | 11 | 12 | 13 | 14
 | Col [] Row [] | 0 | 1 | 2 | 3 | 4 | 5 | 6 | 7 | 8 | 9 | 10 | 11 | 12 | 13
1 | 0 | Esc | F1 | F2 | F3 | F4 | F5 | F6 | F7 | F8 | F9 | F10 | F11 | F12 | PrtScr
2 | 1 | `/~ | 1 | 2 | 3 | 4 | 5 | 6 | 7 | 8 | 9 | 0 | Minus | Equal | BckSpc
3 | 2 | Tab | Q | W | E | R | T | Y | U | I | O | P | [ | ] | \
4 | 3 | L-Shift (CpsLk) | A | S | D | F4 | G | H | J | K | L | ; | ' | Enter
5 | 4 | L-Shift | Z | X | C | V | B | N | M | , | . | / | R-Shift | Up | Pause
6 | 5 | L-Ctrl | LGUI / Win | Alt | Space | R-Alt | Fn (Mo) | Left | Down | Right | End | PgDown | PgUp | Home | Del
 |  | Notes:
 |  | Caps Lock does not get used in qmk layout, as the is no LED for signaling Caps Lock is active.
 |  | Caps Lock is set to Fn+CapsLock

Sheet: andimoto6064
 | ArduinoProMicro |  |  |  |  |  |  |  | Layout | andimoto6064
Row | Col | 1 | 2 | 3 | 4 | 5 | 6 | 7 | 8 | 9 | 10 | 11 | 12 | 13
 | Col [] Row [] | 0 | 1 | 2 | 3 | 4 | 5 | 6 | 7 | 8 | 9 | 10 | 11 | 12
2 | 1 | Esc `/~ | 1 F1 | 2 F2 | 3 F3 | 4 F4 | 5 F5 | 6 F6 | 7 F7 | 8 F8 | 9 F9 | 0 F10 | Minus F11 | Equal F12
3 | 2 | Tab | Q | W | E | R | T | Y | U | I | O | P | [ | ]
4 | 3 | L-Shift/ Reset | A | S | D | F4 | G | H | J | K | L | ; | ' | Enter
5 | 4 | L-Shift | Z | X | C | V | B | N | M | , | . | / | R-Shift | Up
6 | 5 | L-Ctrl | LGUI / Win | Alt | Space | Fn (Mo) | App/ Context | Left | Down | Right | Del | \ | | BkSpc
 |  | Notes:
 |  | Caps Lock does not get used in qmk layout, as the is no LED for signaling Caps Lock is active.
 |  | Caps Lock is set to Fn+Shift
 |  | Caps Lock and Fn do a Reset on Arduino Pro Micro

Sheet: andimoto_smallTKL_iso
 | Teensy 2 |  |  |  |  | Layout | andimoto smallTKL iso
Row | Col | 1 | 2 | 3 | 4 | 5 | 6 | 7 | 8 | 9 | 10 | 11 | 12 | 13 | 14 | 15 | 16 | 17
 | Col [] Row [] | 0 | 1 | 2 | 3 | 4 | 5 | 6 | 7 | 8 | 9 | 10 | 11 | 12 | 13 | 14 | 15 | 16
1 | 0 | Esc | - | F1 | F2 | F3 | F4 | N/A | F5 | F6 | F7 | F8 | F9 | F10 | F11 | F12 | PrtScr | Pause
2 | 1 | ^ | 1 | 2 | 3 | 4 | 5 | 6 | 7 | 8 | 9 | 0 | ß / ? | ` | N/A | BckSpc | Ins | Pos1
3 | 2 | Tab | N/A | Q | W | E | R | T | Z | U | I | O | P | Ü | * / ~ | N/A | Del | End
4 | 3 | Shft | N/A | A | S | D | F | G | H | J | K | L | Ö | Ä | ' / # | Enter | N/A | N/A
5 | 4 | LShft | < / > | Y | X | C | N/A | V | B | N | M | ; / , | . / : | RShft | N/A | Up | N/A | N/A
6 | 5 | RStrg | Win | Alt | N/A | N/A | N/A | Space | - | - | - | Alt | Fn | Strg | Left | Down | Right | N/A
 |  | Notes:
 |  | Caps Lock does not get used in qmk layout, as the is no LED for signaling Caps Lock is active.
 |  | Caps Lock is set to Fn+CapsLock

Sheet: andimoto75Q1-iso
 | Teensy 2 |  |  |  |  | Layout | andimoto75Q1-iso
Row | Col | 1 | 2 | 3 | 4 | 5 | 6 | 7 | 8 | 9 | 10 | 11 | 12 | 13 | 14 | 15 | 16 | 17
 | Col [] Row [] | 0 | 1 | 2 | 3 | 4 | 5 | 6 | 7 | 8 | 9 | 10 | 11 | 12 | 13 | 14 | 15 | 16
1 | 0 | Esc | F1 | F2 | F3 | F4 | F5 | F6 | F7 | F8 | F9 | F10 | F11 | F12 | Ins | Del
2 | 1 | ^ | 1 | 2 | 3 | 4 | 5 | 6 | 7 | 8 | 9 | 0 | ß / ? | ` | BkSp | PgUp
3 | 2 | Tab | Q | W | E | R | T | Z | U | I | O | P | Ü | * / ~ | - | PgDn
4 | 3 | Shft | A | S | D | F | G | H | J | K | L | Ö | Ä | ' / # | Enter | Home
5 | 4 | LShft | < / > | Y | X | C | V | B | N | M | ; / , | . / : | - / _ | RShift | Up | -
6 | 5 | RStrg | Win | Alt | - | - | - | Space | - | - | Alt | Fn | Strg | Left | Down | Right
 |  | Notes:
 |  | Caps Lock does not get used in qmk layout, as the is no LED for signaling Caps Lock is active.
 |  | Caps Lock is set to Fn+CapsLock

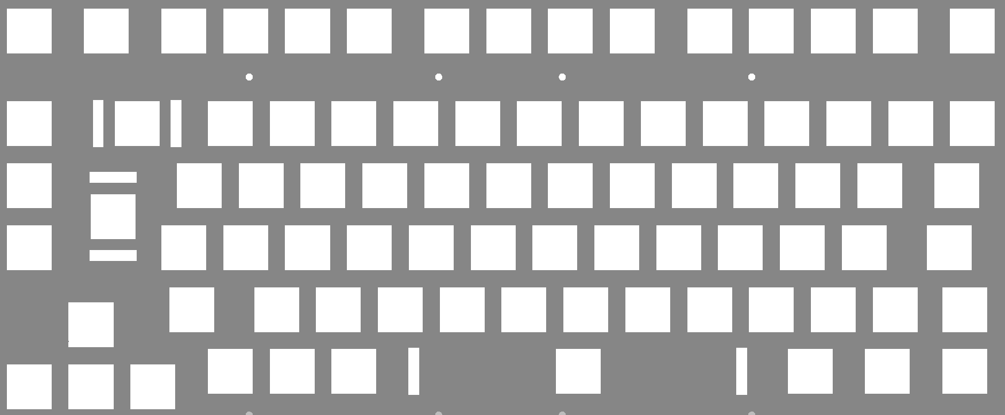
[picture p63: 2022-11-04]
wiring_sheets/andimoto75Q1-iso/andimoto75Q1-iso-mirrored.png

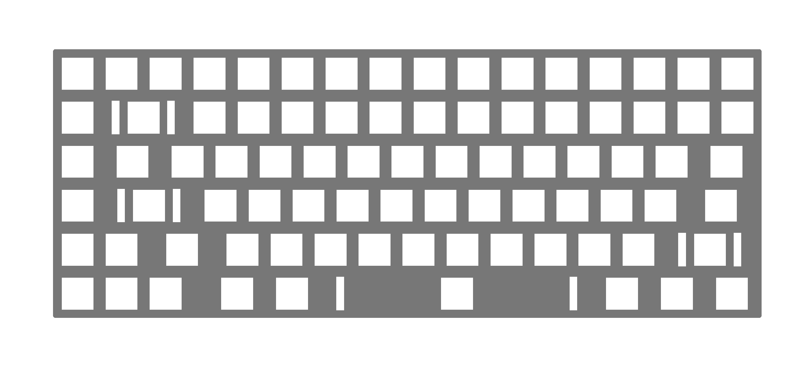
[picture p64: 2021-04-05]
wiring_sheets/andimoto7583/andimoto7583_mirrored.png

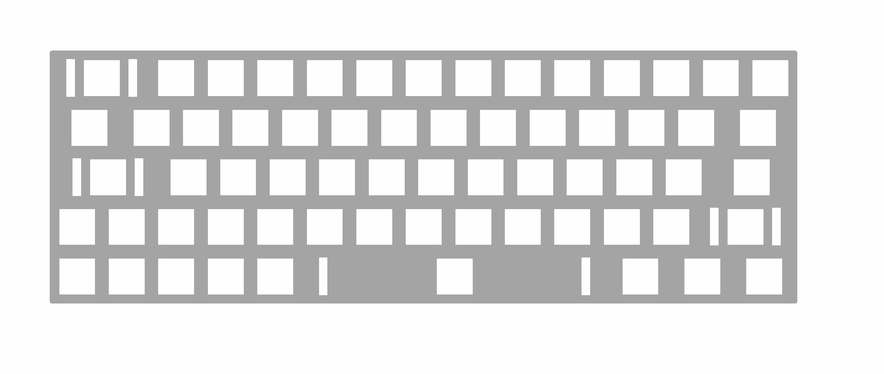
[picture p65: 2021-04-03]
wiring_sheets/andimoto6064/andimoto6064_mirrored.png

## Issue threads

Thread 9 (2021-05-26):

Can this be used with a regular PCB

kandji-edwin, 2021-05-26:
Awesome project! Can this be used with a regular keyboard PCB, or is it only suitable for hand wired keys attached to an Arduino?

In particular, I have an Makerdiary M60: https://makerdiary.com/collections/mechanical-keyboard

andimoto, 2021-05-26:
Thanks!
I think it could work with some modifications:
- PCB should fit inside the case
- USB cut-out should be placed correctly
- Stand-offs for the lid screws should be much lower, and also placed to fit some holes of the pcb
- Bigger Problem: fixing the lid properly to the case (because screw stand-offs would be smaller and already fixing the pcb inside). Maybe it works if pcb gets fixed by some hex spacers and the lid gets fixed on top of that....

Just a few ideas...

kandji-edwin, 2021-05-26:
Thanks for the tips. While I'm a programmer by trade, I've only just started 3d printing and using openscad 2 weeks ago.

I'll keep you posted on how my attempt goes, though

Closed 2022-08-20.

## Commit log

2021-02-12 moved 75erKeyboard into new project repo
    [7583_1Riser_2x.stl, 7583_LCase.stl, 7583_LLid.stl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]
2021-02-12 README.md und template_to_copy.scad aktualisiert
    [template_to_copy.scad]
2021-02-13 iso enter calculation added
    [andimoto_smallTKL_iso.scad, keyboardParts.scad]
2021-02-13 added iso layout keyboard
    [andimoto_smallTKL_iso.scad]
2021-02-14 added correct iso enter simulation call to keyV2
    [keyboardParts.scad]
2021-02-14 .gitignore und test_isoDE_7583.stl aktualisiert
    [test_isoDE_7583.stl]
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2021-02-17 more readme stuff and many pictures!!
    [andimoto6061.scad, andimoto_smallTKL.scad]
2021-02-18 README.md und keyboardParts.scad aktualisiert
    [keyboardParts.scad]
2021-02-19 added case locks, changed calculations for case
    [keebCase.scad]
2021-02-21 added more tolerance into lock cutout
    [keebCase.scad]
2021-03-02 README.md und andimoto_smallTKL_iso.scad aktualisiert
    [andimoto_smallTKL_iso.scad]
2021-03-03 andimoto_smallTKL_iso.scad und keyboardParts.scad aktualisiert
    [andimoto_smallTKL_iso.scad, keyboardParts.scad]
2021-03-04 fixed iso enter position
    [keyboardParts.scad]
2021-03-04 added pcbShift to move pcb and usb cutout
    [andimoto6061.scad, andimoto7583.scad, andimoto_smallTKL.scad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]
2021-03-04 rebuild stl files with new changes, moved screw standoffs
    [7583_LCase.stl, 7583_LLid.stl, 7583_RCase.stl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]
2021-03-06 changed pcb cutout and clamp
    [andimoto_smallTKL_iso.scad, keyboardParts.scad]
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2021-03-06 fixed shitty pcb holdness!
    [keyboardParts.scad]
2021-03-06 added stl files for andimoto smallTKL iso
    [andimoto_smallTKL_iso.scad, andimoto_smallTKL_iso_CaseComplete.stl, andimoto_smallTKL_iso_CaseL.stl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]
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2021-03-13 README.md, andimoto6061.scad und 20 weitere dateien aktualisiert...
    [andimoto6061.scad, andimoto7583.scad, andimoto_smallTKL.scad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]
2021-03-13 wrist330L.stl, wrist330R.stl und 2 weitere dateien aktualisiert...
    [wrist330L.stl, wrist330R.stl, wrist330_complete.stl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]
2021-03-13 README.md, keebCase.scad und 2 weitere dateien aktualisiert...
    [keebCase.scad]
2021-03-13 7583_CaseComplete.stl und 7583_LidComplete.stl aktualisiert
    [7583_CaseComplete.stl, 7583_LidComplete.stl]
2021-03-13 added usb port sizes for teensy and arduino pro micro
    [andimoto6061.scad, andimoto7583.scad, andimoto_smallTKL.scad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]
2021-03-13 added TKL designs, changed readme
    [andimotoTKL.scad, andimotoTKL_caseComplete.stl, andimotoTKL_caseL.stl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]
2021-03-14 andimoto6064.scad und andimoto6064.png aktualisiert
    [andimoto6064.scad]
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2021-03-14 build.sh, template_to_copy.conf und template_to_copy.scad aktualisiert
    [template_to_copy.scad]
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2021-03-16 added qmk sheets for teensy2 and arduino pro micro
    [qmk_layout_sheet.ods]
2021-03-17 andimoto_smallTKL_iso.png, andimoto_smallTKL_iso_mirrored.png und 7 weitere dateien aktualisiert...
    [qmk_layout_sheet.ods]
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2021-03-20 andimoto6061.scad, andimoto6064.scad und 16 weitere dateien aktualisiert...
    [andimoto6061.scad, andimoto6064.scad, andimoto6064_keyboardRiser.stl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]
2021-03-21 README.md, andimoto6061.scad und 7 weitere dateien aktualisiert...
    [andimoto6061.scad, andimoto6061_keyboardRiser.stl, andimoto6061_lid.stl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]
2021-03-21 generated new stl files, readme changed
    [7583_1Riser_2x.stl, 7583_CaseComplete.stl, 7583_LCase.stl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]
2021-03-23 andimotoTKL.scad und keyboardParts.scad aktualisiert
    [andimotoTKL.scad, keyboardParts.scad]
2021-03-24 andimoto6064.scad, andimoto6064_keyboardRiser.stl und 6 weitere dateien aktualisiert...
    [andimoto6064.scad, andimoto6064_keyboardRiser.stl, andimoto6064_lid.stl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]
2021-04-02 added fRowSeparator and function getExtraFRow() to calculate extra value to move 1st row up
    [keyboardParts.scad]
2021-04-02 added fRow separation to keycap simulation and half case calculation
    [keyboardParts.scad, template_to_copy.scad]
2021-04-02 fixed frow lid calculation, added new stl files for tkl keyboards
    [andimoto6061.scad, andimoto6064.scad, andimoto7583.scad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]
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2021-04-04 README.md, andimotoSmallTKLiso.scad und andimoto_smallTKL_isoBlue.png aktualisiert
    [andimotoSmallTKLiso.scad]
2021-04-05 added wiring sheets for andimoto7583, restructured directories
    [qmk_layout_sheet.ods]
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2021-08-13 fixed incorrect skirt setting
    [keyboardParts.scad]
2021-08-13 skirt calculation fix
    [keyboardParts.scad]
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2021-08-30 added screwSpacerRotation var to rotate stems of screws
    [andimoto6061.scad, andimoto6064.scad, andimoto7583.scad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]
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2021-09-02 fixed macropad lid pcb holder for setting arduino promicro
    [macropad.scad, macropad_lid_5x2_ProMicro.stl]
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2021-12-07 fixed shit - keyboardParts.scad, numpad.scad und template_to_copy.scad aktualisiert
    [keyboardParts.scad, numpad.scad, template_to_copy.scad]
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2022-06-16 added key profile selection to select from KeyV2 lib
    [andimoto6061.scad, andimoto6064.scad, andimoto7583.scad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]
2022-06-16 offset arrow switchholes and minnimal change in calculation of holes and case-stabilizer
    -added cutThrough variable to keyboardParts.scad to allow to cut everything under the switchholes. this avoids case-stabilizers at iso-enter and switches with smaller offsets.
    - this case should have thicker skirts to have more space for the offset arrow switches.
    [andimoto75Q1-iso.scad, keyboardParts.scad]
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2022-07-31 added dual color sim to case - save commit
    [andimoto7583.scad, andimoto75Q1-iso.scad, keyboardParts.scad]
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2022-08-15 added new variables, arrays and calls to other keebs
    [andimoto6061.scad, andimoto6064.scad, andimoto7583.scad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]
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2022-09-20 fixed iso de q1mock
    [andimoto75Q1-iso.scad, andimotoSmallTKLiso.scad]
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2022-09-20 added stl files of andimotoQ1 ansi us layout
    [andimoto75Q1-caseL-teensy2.stl, andimoto75Q1-caseR-teensy2.stl, andimoto75Q1-frameL.stl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]
2022-09-20 added fixed stl for andimotoQ1-iso
    [andimoto75Q1-iso-caseL-teensy2.stl]
2022-10-18 added new stl files for TKLiso - teensy2 and promicro
    [andimotoSmallTKLiso.scad, andimotoSmallTKLiso_ALL-Case-ProMicro.stl, andimotoSmallTKLiso_ALL-Case-Teensy2.stl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]
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2024-02-24 Update Readme.md, Unnamed-andimoto7583_keyboardRiser.mtl, Unnamed-andimoto7583_keyboardRiser.obj, and 18 more files
    [Unnamed-andimoto7583_keyboardRiser.obj, Unnamed-andimoto7583_lid.obj, Unnamed-andimoto7583_lidL.obj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]
